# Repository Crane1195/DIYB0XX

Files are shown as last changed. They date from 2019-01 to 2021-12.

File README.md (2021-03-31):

# Crane's DIY B0XXes
### Version 3 - LaserCutB0XX

### Version 2 - AluminumB0XX

### Version 1 - WoodB0XX


The B0XX is a controller designed for Super Smash Brothers Melee, with ergonomics being the number one priority. It is

    Designed by Aziz “Hax$” Al-Yami
    Produced & Engineered by Stephen “Streamlord” Kasmir
    Programmed & Engineered by Kyle “simple” McDowell
    Logo & Art  by Jacqueline "Jisu" Choe

More information regarding the B0XX and links to preorder it are found here.

https://b0xx.com/

To contact me with any comments or questions regarding the info in this repo, join my Discord server here: https://craneslab.xyz/discord

I wanted to try this layout before the product launches, so I created a B0XX from raw materials (later a prefabricated case), arcade hardware, and an Arduino.

I first created a B0XX using wood, which you can see the process of in the MyWoodB0XX folder, but did not like the feeling of its surface and its large size.

I then made one in a much smaller aluminum case that I purchased from Digikey, and have had an acrylic panel laser cut with the layout I drew in Autodesk Inventor. Info about it and its upgrades can be found in the MyAluminumB0XX folder.

I have now made one using a laser cut wooden case, and internally it uses my new GCCPCB which allows for much cleaner internals, and many new features. More info about this build and the GCCPCB can be found in the MyLaserCutB0XX folder.

The process of making the detachable GameCube cable used with my Aluminum B0XX is detailed in the Detachable Cable folder.

The MiniB0XX folder contains files pertaining to a 3d printable case that is similar in size and potential functionality to my Aluminum B0XX.

The code folder includes the most up to date software for flashing to an Arduino.

If sharing any of the files/information found here, give credit where credit is due.

### Support my work

Do note, all Amazon links are affiliated, meaning I get a kickback when you buy anything using these links, and you pay the normal price of the thing. I figure it's a good way for people who want to support me to be able to without any additional cost.

I also set up a donation link for people who appreciate my work and wish to donate. Donations are greatly appreciated, but are far from necessary:

https://www.paypal.com/donate/?hosted_button_id=NFDEML5FKR8N8

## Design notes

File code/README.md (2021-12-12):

# DIYGCC v1.209 code by Crane.

# Deprecated

This firmware has been succeeded by [CL-FW](https://github.com/Crane1195/CL-FW). Consult the CL-FW README for more information and a new installation guide.

---

This is code designed with 16 mhz Arduinos in mind such as the Arduino Mega 2560, Arduino Micro, Arduino Nano, etc.

Release Page: https://github.com/Crane1195/DIYB0XX/releases

## Variants

- `DIYGCC_GC`
  - __**Using:**__
    - Mega2560, Nano, Uno
    - [GameCube circuit](https://cdn.discordapp.com/attachments/557665530677559307/680513973694627847/micro_diyb0xx_schematic.png)
  - __**Supports:**__
    - GameCube/Wii/GCC to USB adapter

- `DIYGCC_GC_And_USB`
  - __**Using:**__
    - Micro, Leonardo, Pro Micro
    - [GameCube circuit](https://cdn.discordapp.com/attachments/557665530677559307/680513973694627847/micro_diyb0xx_schematic.png)
  - __**Supports:**__
    - GameCube/Wii/GCC to USB adapter
    - PC via a USB cable

- `DIYGCC_USB`
  - __**Using:**__
    - Micro, Leonardo
  - __**Supports:**__
    - PC via a USB cable

- `DIYGCC_USB_ProMicro`
  - __**Using:**__
    - Pro Micro
  - __**Supports:**__
    - PC via a USB cable

- `DIYGCC_USB_Switch` - [Read this README for instructions](https://github.com/Crane1195/DIYB0XX/blob/master/code/DIYGCC_USB_Switch_Beta/README.md)
  - __**Using:**__
    - Micro, Leonardo, Pro Micro
  - __**Supports:**__
    - Switch via a USB cable

- `Smashbox`
  - __**Using:**__
    - Hitbox Smashbox
  - __**Supports:**__
    - GameCube/Wii/GCC to USB adapter
  - Here is a tutorial for how to flash it to a Smashbox. Use the code from the most recent release on this repo, as it is the most up to date.
https://github.com/zandm7/DIY-SmashB0XX/blob/master/code/README.md

## SOCD Options
You can choose between 2ip, 2ip with no reactivation, and neutral to resolve simultaneous opposite cardinal direction (SOCD) inputs. This applies to both the control and c stick.

#### 2ip works like this:
* Press left. Character moves left.
* While still pressing left, press right. Character moves right.
* While still pressing left, stop pressing right. Character moves left again.

#### 2ip with no reactivation (The method the B0XX uses) works like this:
* Press left. Character moves left.
* While still pressing left, press right. Character moves right.
* While still pressing left, stop pressing right. Character will not move.

#### Neutral works like this:
* Press left. Character moves left.
* While still pressing left, press right. Character stops moving.
* While still pressing left, stop pressing right. Character moves left again.

## Game profiles
Currently there are 4 game profiles. Melee, Ultimate, PM, and RoA. While plugging in the controller:
* Hold no buttons for Melee.
* Hold B for Ultimate.
* Hold X for PM.
* Hold Z for RoA (only on PC over USB)

## USB Mode
If you are using the firmware with both GC and PC support, hold C-Down while plugging in to enter PC mode.

If you are using any PC supporting firmware, hold ModY on plugin to enter keyboard mode.

## DPAD Toggle
DPAD is enabled by holding ModX and ModY and pressing C-Up/down/left/right.

## Installation
The firmware currently utilizes Nicohood's Nintendo library found here :

https://github.com/NicoHood/Nintendo

and MHeironimus' Arduino Joystick Library found here :

https://github.com/MHeironimus/ArduinoJoystickLibrary

If this is the first time you have used these libraries, press Clone or download, and press Download ZIP on these repos.

Download YourVariant.zip from the latest release here https://github.com/Crane1195/DIYB0XX/releases. Copy the YourVariant folder out from this .zip to a convenient location. You can place the ArduinoJoystickLibrary-master.zip file and the Nintendo-master.zip file here too.



Your folder should look something like this.

Another thing you will need is the Arduino IDE, which is found here :

https://www.arduino.cc/en/Main/Software



After installing the Arduino IDE, open YourVariant.ino within it, and add the libraries using this menu option.



Navigate to where you have the YourVariant folder, and double click one, then repeat the process for the other. You will only need to install these libraries and the Arduino IDE once. For future updates, you will just have to download the new code, and upload it using the method below.



In this menu, change the board to be whichever board you are using. If you are using a Pro Micro you can just use the Micro option. 



Before plugging in the Arduino, look and see what Ports are there. On this machine, there is COM1, but on my other machine, I had none.



Plug in the board via USB, and check this menu again, you should see another COM port show up. For both of my computers, it will also say "Arduino Micro" next to the port, but it is possible it will not. What should always happen though, is a port should show up when you plug in the board, and should disappear when you unplug the board (make sure you close the menu and reopen it to refresh the list). This port is the port for your Arduino, so select it.



If you are using GC firmware, you will need to change the value here to match which pin you connected your data line to.



On any of these firmwares, you will need to change this pinout section to match which pins you connected your buttons to.



Click this button to upload the firmware to the Arduino.



This section of the IDE will say Compiling Sketch, then Uploading, then Done Uploading. When it says Done Uploading, the board is ready to use, and can be unplugged.

## Contact info
Let me know if you have any issues with the code in my Discord Server:
https://craneslab.xyz/discord

## Support my work

Do note, all Amazon links are affiliated, meaning I get a kickback when you buy anything using these links, and you pay the normal price of the thing. I figure it's a good way for people who want to support me to be able to without any additional cost.

I set up a donation link for people who appreciate my work and wish to donate. Donations are greatly appreciated, but are far from necessary:

https://www.paypal.com/donate/?hosted_button_id=NFDEML5FKR8N8

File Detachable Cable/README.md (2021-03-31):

# Crane's Detachable Gamecube Cable Guide


Here you will find all the information needed to make a detachable cable for a custom Gamecube controller/fightstick.

If you have any questions regarding the process, feel free to ask in my Discord server here https://craneslab.xyz/discord

GCC stands for GameCube Controller. I will use this acryonym a lot.

## Required Parts / Tools


- OEM GCC Cable OR GCC extension cable
    - If you have a broken GCC for parts, you can harvest its cable and use that. Otherwise, a GCC extension cable will work. If you have neither, a broken GCC costs much more, but its cable is guaranteed to be high quality, as it is OEM. An extension cable is much cheaper (talking ~$15 dollars compared to ~$3), but some of them are not high quality.
    - I made two custom cables from Kitsch-Bent extension cables and they work perfectly. Here is a link to them, select NGC from the drop down menu. They only cost $2.50, and shipping is ~$5.00, so I got multiple.
    - http://store.kitsch-bent.com/product/extension-cables

- Wire stripper. This is used to remove the protective outer shell of the GCC cable.
    - I used the 8/10 gauge cutter on mine.

- RJ45 Crimp Kit
    - Here's the kit I used. This comes with both the crimping tool, and the connectors.
    - https://amzn.to/2QNOFHn

- Neutrik NE8FDP
    - This is the female connector that gets installed in the case of the fightstick; comes in black and silver. Here's a link to the black one I use.
    - https://amzn.to/3frK87Z

- Neutrik NE8MC
    - This is the male connector, that is installed around the custom cable. The cable works without this, but this makes it much more durable and secure; also comes in black and silver. Here's a link to the black one I use.
    - https://amzn.to/39usFYx

- Multimeter
    - If you are not using an OEM GCC cable, to be safe, you will need to check which wire is which signal. I will post what my wires are below. If you use a Kitsch-Bent extension, they will likely be the same, but not necessarily. It is possible that they have changed their supplier which would change the wiring.

## Making the Cable



1. Cut the female end off of the extension cable, or take apart a GCC and cut the cable as close to its connector as possible.



2. Strip off about 1 cm of the outer shell. The wires here are too long, so I trimmed them down as seen below, using a wire cutter.



3. Flatten all the wires in a way that makes them the least strained. In the cable, they are in a hexagonal prism formation, so try and keep the left wires close to the left, right to right, and middle to middle.



4. Insert the cables into a connector like so, with each wire going into its own channel.



5. This is the wiring setup I am using. As shown in the graphic on the right, the 8 channels of an RJ45 jack are numbered from left to right when the connector is pointing away from you, and the tab is pointing down.

There are different standards of RJ45, but the T-568B RJ45 cables are what you will probably find when getting an "ethernet" cable, and it is what I have on hand.

Row 2 shows which channels the wires from my GCC extension cable are in, Row 3 shows the T-568B wires, and row 4 shows what    function each wire serves for this cable. I will show how I derived this further down.



6. Push the connector into the side of the crimping tool that it fits into (it only fits one way) while keeping the cable pushed all the way into connector. I clamp it down 3 times with full force. The cable should now be clamped down by the plastic connector.


7. To find which cable does what, I then cut a ethernet cable in half, cut open its out shell, and strip the ends of the wires. I used a 26 gauge wire stripper for this.


8. I then plugged the GCC to RJ45 cable and the cut ethernet cable into the Neutrik ethernet passthrough.


9. Using a multimeter on continuity mode, attach one lead to one of the exposed ethernet wires, and then stick the other lead into the GCC male connector, and find which pin corresponds to which wire.


10. To double check this, you can check the wires voltages as well. Using the same setup as before, with GCC to RJ45 to Neutrik to RJ45 to breakout. Make sure the exposed wires stay fanned out like in the picture to prevent a short circuit. Hook up the GCC plug to a GC/Wii/Adapter, and read the difference in voltage between the wires you think are 5V/3.3V/Data and ground. The 5V one will read ~4.7V, the 3.3V one will read ~3.1V, and the data one changes, but is less than ~3.3V and greater than ~0.1V.

Using both of these methods, I derived the chart you see above for my cable. If you use a different extension cable, or a different standard of RJ45 ethernet cable, or different wire order, our charts will not be the same. If you use a Kitsch-Bent extension cable, and line up its wires just like I did, it'll probably be the same, but you should check anyway just to be safe.


11. Follow the instructions here to install the NE8MC around your new cables RJ45 plug.

https://www.neutrik.com/media/8070/download/ethercon-cable-connector-ne8mc.pdf?v=1

## Installation Into a Fightstick


12. I used a unibit to drill a ~24mm hole in this aluminum case, inserted the NE8FDP faceplate into the hole, marked where the screw holes should be, and drilled 1/8" holes for them.


13. Inside the case, I cut that ethernet breakout cable down very short, trimmed the wires to be just long enough, and then soldered them into place. For more information about this wiring schematic, check out the README here. https://github.com/Crane1195/DIYB0XX/tree/master/MyAluminumB0XX

## Results

I ended up making a second one as I wasn't taking pictures as I went for the first one. As previously mentioned, it works without the NE8MC, but I'd still recommend it for a more secure connection.

Once again, let me know in my [Discord Server](https://craneslab.xyz/discord) if you have any questions.

## Support my work

Do note, all Amazon links are affiliated, meaning I get a kickback when you buy anything using these links, and you pay the normal price of the thing. I figure it's a good way for people who want to support me to be able to without any additional cost.

I also set up a donation link for people who appreciate my work and wish to donate. Donations are greatly appreciated, but are far from necessary:

https://www.paypal.com/donate/?hosted_button_id=NFDEML5FKR8N8

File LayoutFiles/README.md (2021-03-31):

# Layout Files

I've made a lot of layout files over time and figured it would make sense to compile some of the useful ones here. Let me know if you interested in any other layout files, I might have made them already and I can add them here.

The PDF folder is for people who want to print the layout to use as a template.

The DXF folder is for people who want to modify the layouts, or get them laser cut.

## USA Laser Cutting Recommendations

https://www.pololu.com/product/749 for laser cutting acrylic and wood, they are very fairly priced and quite quick.

https://sendcutsend.com/ for laser cutting metals, they have incredible prices for laser cut metals, are super fast, and offer free shipping.

## Top Panel Laser Cutting Advice

### MX Form Factor Keyboard Switches

If you are using MX like keyboard switches, I recommend using a 1.5mm steel switch plate from SendCutSend. 1.5mm is what you need for the switches to snap in properly, and steel is super rigid and not too expensive. Acrylic and wood would be far too flimsy, aluminum would probably be fine but a bit less rigid than steel, and brass/carbon fiber would work well but be far more expensive.

### Snap In Buttons

If you are using 24mm snap in buttons (like Sanwa OBSX-24) and an acrylic or wood top panel from Pololu:

Sanwas will only clip into panels that are <= 3mm thick with 24mm holes. Just a 3mm thick top acrylic panel though will flex in the middle. To solve this, I add another 3mm panel beneath the top panel. This one has 26mm holes, which allows the buttons to still clip in.

```
Top Top panel    - 3mm thick - 24mm holes
Bottom Top Panel - 3mm thick - 26mm holes
```

If you are using 24mm snap in buttons (like Sanwa OBSX-24) with an aluminum or ACM top panel from SendCutSend, ~3mm is enough to not flex at all.

### Screw in Buttons

If you are using Crowns screw in buttons you could use just one 6mm acrylic or wood panel with 24mm holes rather than two 3mm ones. (Unless you want art, then you'd want a clear 3mm panel and some color 3mm panel)

And like with snap in buttons, just a 3mm aluminum or ACM panel is fine too.

### Support my work

Do note, all Amazon links are affiliated, meaning I get a kickback when you buy anything using these links, and you pay the normal price of the thing. I figure it's a good way for people who want to support me to be able to without any additional cost.

I also set up a donation link for people who appreciate my work and wish to donate. Donations are greatly appreciated, but are far from necessary:

https://www.paypal.com/donate/?hosted_button_id=NFDEML5FKR8N8

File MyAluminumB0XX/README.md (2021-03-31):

# Crane's DIY Aluminum B0XX


The B0XX is a controller designed for Super Smash Brothers Melee, with ergonomics being the number one priority. It is

    Designed by Aziz “Hax$” Al-Yami
    Produced & Engineered by Stephen “Streamlord” Kasmir
    Programmed & Engineered by Kyle “simple” McDowell
    Logo & Art  by Jacqueline "Jisu" Choe

More information regarding the B0XX and links to preorder it are found here

https://b0xx.com/

While my first DIY B0XX project was functional, it had room for improvement. This time, I have chosen to purchase an aluminum case from Digikey to use as the chassis, and I have drawn a face plate, which was laser cut out of acrylic from Pololu. The prefab aluminum case was chosen to make all three dimensions smaller. It is much more portable now as a result. The laser cut acrylic plate has perfectly spaced holes, and is much smoother than the wood coated in polycrylic.

On top of this, I have done two modifications to the design which increase overall functionality.



The first of which a detachable RJ45 to Gamecube cable, and the second is an internal Gamecube to USB adapter with the extra three ports available to use outside the case.

If you have any questions regarding this build, feel free to ask me in my Discord server (https://craneslab.xyz/discord) or in direct message @Crane#1195 .

## Components

### Aluminum Case


The case used for this build is a 12" x 8" x 2" aluminum prefab that I ordered from Digikey.

https://www.digikey.com/product-detail/en/hammond-manufacturing/1444-22/HM267-ND/247996

This case's edges are pretty sharp, the holes on mine did not match up exactly to its datasheet, and it got pretty scratched up while I was modding it, but it is pretty decent for the price of ~$40 dollars shipped.

A bit of sanding solves the sharp edges.

I highly reccomend measuring the holes on your unit if you are making a panel for the top like I did. I might have been unlucky, but it might be normal.

It comes with an adhesive protective film on all sides if I recall correctly. Leave these on the case while working on it.

They also make a similar case to this one, but in a 16" x 8" x 2" form factor. The larger size comes in both aluminum:

https://www.digikey.com/product-detail/en/hammond-manufacturing/1444-26/HM269-ND/247998

and steel:

https://www.digikey.com/product-detail/en/hammond-manufacturing/1441-26BK3/HM1493-ND/460097

I have not used the steel variant, but I would imagine it would be more scratch resistant and probably stronger.

### Laser Cut Acrylic Button Panel


I designed this button panel based on the layout of the MiniB0XX made by Simple. You can find drawing/PDF files of this layout here:

https://github.com/Crane1195/DIYB0XX/tree/master/MyAluminumB0XX/AcrylicPlate

I sent drawing file (.dwg) to Pololu, who have an affordable acrylic laser cutting service that you can find here:

https://www.pololu.com/product/749



They have tons of options, and I chose this one. It is a slightly translucent matte finish white panel (the bottom side is glossy, but it is inside the case).

I highly recommend them. I have ordered two panels from them so far, and both turned out perfect. Do note though, this panel is below their minimum cost of $25, so if you have anything else you would like laser cut, they can add that to the order to be cost efficient.

The screw holes in the drawing file I linked is based on the 12" x 8" case's datasheet's screw placements, and as previously mentioned, these did not work perfectly for my case. I had to use different screws and angle them for the top two. Measuring your own case and editing the drawing file would be ideal, and if you do not know how to use a CAD software, or do not have one, I can edit the drawing for you given your measurements. Alternatively you could just roll the dice and hope your case is good enough, or angle screws like I did.

Personally, I use just one 3mm acrylic panel for the top. If you push in the middle of it, there is a bit of flex, but it is not enough to bother me. If this would bother you, or you want to easily use art under the buttons, you can get a second panel, but with 28mm holes to put under the top 24mm holes panel. This way, the buttons snap into the top panel, and just pass through the second. For art, you could get a clear top, and whatever color bottom, and put the art inbetween. Once again, if anyone who can not use a drawing editor wants me to make this into a file, let me know.

### Detachable RJ45 to GCC Cable

This is a massive upgrade over the attached cable used previously. Besides the fact that the cable I used was in bad shape and from a beat up OEM controller I found on eBay, an attached cable does not really have anywhere to go outside of a box controller. Wrapping it around damages the cable, and it makes the controller much more of a hassle to travel with. To see how this cable is made, check out this guide I wrote on the topic: https://github.com/Crane1195/DIYB0XX/tree/master/Detachable%20Cable

### Internal GCC to USB adapter

This is an interesting addition that could be quite useful for some people, but I am not really one of them. Basically, you take the Nintendo GCC to USB adapter out of its case, solder wires to the pads of a GC port on a Gamecube to USB adapter, and route those to the same lines of your normal GCC cable. What this means is that you can use the controller like a normal Gamecube controller with the RJ45 to GCC cable, or you can plug the GC adapters USB cable into a Switch/WiiU/PC to avoid using an external controller adapter.

To do this, I wanted to remove the gray usb cable to save space in the case, and solder wires to the back of the adapters PCB to access 5v, GND, 3v, and data.


Here is a spreadsheet detailing what each pin of the connector / header on board does.


Basically you want to remove / cut wires 1, 2, and 5, and split the cable in half as seen below.


Here is the finished modified GCC adapter. I forgot to get a labeled pinout of the pads on the back of the adapter as to which is 5v, GND, 3V, and data, so if you want to do something like this, you'll need to use a multimeter continuity test to figure out which is which.

### The Internals

Initially, I had used the same Mega2560 and logic converter as before, and soldered each of the GCC adapters lines (5v, GND, 3v, Data) to the RJ45 lines.

### Wiring Schematic

The wiring schematic is the same as my first DIY, but now has the GCC adapters lines attached as well.

### Completed interior

Not the cleanest thing ever, but here was the completed interior. The left Neutrik is for the Dween, the middle is for the RJ45 Gamecube port, and the right is for the GCC to USB adapter.

### Updated interior

I made a PCB to make building Gamecube controllers a lot easier and to have more features. I call it the GCCPCB. A brief synopsis of the benefits are:

* The entire circuit is all done by the board.
* Buttons don't need to be spliced to jumper cables and can just be plugged into screw terminals.
* It's very compact.
* A port for a detachable cable is built in (either RJ45 or USBC).
* A 10x2 pin connector is on board to passthrough button signals to a Brook board.
* Native PC controller support. No need for a GCC to USB adapter for PC.
* Nunchuk port to use an analog stick instead of the digital stick / modifiers.

If you are interested in finding out more about the GCCPCB, check out https://www.craneslab.xyz/projects/s


Here is the final interior. I put a four pin header on the board to allow access to the 5V, GND, 3V, and Data lines so I could hook up my GCC to USB adapter. I plugged the GCC adapter into the GCCPCB USB port, which means that it is accessible using a RJ45 to USB cable. The Arduino is plugged into a USB Neutrik, which I use for Native PC control and updating the firmware.

### Conclusion / Contact

Overall, this controller has been a really solid test bench for various projects I've been working on. First the internal USB to GCC adapter, then my mechanical switch boards that I used to replace the Sanwa SW68s (maybe more info on these coming soon, they aren't perfect yet), and now to work on my GCCPCB.

If you have any questions about this build, the GCCPCB, or anything else, feel free to message me on Discord @Crane#1195, or to join my Discord server, https://www.craneslab.xyz/discord, where I'll be posting updates about the various projects I am working on.

### Support my work

Do note, all Amazon links are affiliated, meaning I get a kickback when you buy anything using these links, and you pay the normal price of the thing. I figure it's a good way for people who want to support me to be able to without any additional cost.

I also set up a donation link for people who appreciate my work and wish to donate. Donations are greatly appreciated, but are far from necessary:

https://www.paypal.com/donate/?hosted_button_id=NFDEML5FKR8N8

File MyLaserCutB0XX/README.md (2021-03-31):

# Crane's Laser Cut DIY B0XX



The B0XX is a controller designed for Super Smash Brothers Melee, with ergonomics being the number one priority. It is

    Designed by Aziz “Hax$” Al-Yami
    Produced & Engineered by Stephen “Streamlord” Kasmir
    Programmed & Engineered by Kyle “simple” McDowell
    Logo & Art  by Jacqueline "Jisu" Choe

More information regarding the B0XX and links to preorder it are found here

https://b0xx.com/

Up until now, I haven't actually made a "perfect" DIY B0XX, which I define as thin, a spread out layout, and high build quality. I've accomplished these three this time, as well as doing art and using my USB-C GCCPCB for the first time.

## The Laser Cut Case

The case is comprised of 5 laser cut layers, all cut by [Pololu](https://www.pololu.com/product/749). A big shoutout goes to simple for the layered case idea.

- Bottom Layer      : 1/4" Wood

- Wall Layer 1      : 1/2" Wood

- Wall Layer 2      : 1/2" Wood

- Top support layer : 1/8" Wood. 26mm holes cut for buttons to pass through.

- Top button panel  : 1/8" Transparent cast acrylic. 24mm holes cut for buttons to snap into.


Here's a picture of all five layers and the hardware to secure it all.


The bottom wall panel has hexagons cut to hold hex nuts within the walls of the case to hold the screws in place. Since the hex nuts are thinner than the wall, I 3d printed hexagon shaped spacers to put underneath the nuts (shoutout to simple for this idea).


The nuts now sit flush with the top of the wall. The second wall is glued on top of this wall, encasing the nuts within the walls.


Here's how it looked after the bottom and the two walls were glued together. The top two panels get screwed into the bottom 3.


I didn't have a way to perfectly align the layers as they were being glued together, so the layers were about 0.3mm off at various points around the case. If anyone plans on doing a case like this, I reccomend figuring out a way to make sure they are perfectly aligned while gluing to prevent this. If I end up doing this again, I will put the same size hole as in the walls in the bottom panel and put a rod through all the panels holes to try and hold it in place. I'd probably then wood fill in the holes in the bottom panel.


I decided to sand the entire thing so that they would be even. This took a long time considering I only have a sanding block.


I then put the acrylic panel on it, and went at it again. I got a lot more of the laser burn off this time as well.


After sanding was done, I used Minwax prestain conditioner, then 2 layers of dark walnut stain, then 3 layers of liquid clear satin polyurethane, then one layer of aerosol polyurethane. Finally I used wood finishing paste wax on top of all that. After all the sanding, polyurethane, and wax, it's about as smooth as my satin hardwood floors.

## Art

Next was art. I printed it on 17"x11" paper, used scissors to cut the rounded edges, put it inbetween the two panels, and used an exacto knife to cut out the button holes. I then used the white spacer in the OBSC-24 button to give me a guide for how small the button art had to be. I used a very small pair of scissors to cut the 24mm art cutouts down to the size they needed to be to fit in the buttons. [Here's a rough guide on that if you are interested.](https://support.focusattack.com/hc/en-us/articles/115002742306-Adding-art-to-buttons-101)

## Ports

I left two gaps in the walls. One for a [USB C feedthrough](https://amzn.to/3ud6Y7w), and the other for a [Nunchuk extension cable](https://amzn.to/3u9P2dJ). The company who makes the USB C feedthrough also makes one with only one port which you can find [here](https://amzn.to/39NfIth).

Here is another [USBC feedthrough](https://amzn.to/2PeNWPh) which is more commonly in stock and is usually cheaper.


I used [this](https://amzn.to/3diyg5o) to secure the USB C feedthrough in place, and the Nunchuk extension is friction fit into place. Both are very secure, and I will eventually get some black PLA and make a spacer above the Nunchuk extension to close that hole.

## Internals

Here you can see the internals. This board is the GCCPCB, made my me. If you are interested in learning more or have any questions about this board and its firmware, feel free to message me about it on Discord @Crane#1195, or to [join my Discord server](https://www.craneslab.xyz/discord) where I post updates about hardware I am working on or firmware updates.
Here's a brief synopsis of its benefits over my previous method of making DIY Gamecube Controllers.
* The entire circuit is all done by the board.
* Buttons don't need to be spliced to jumper cables and can just be plugged into screw terminals like on a Brook board.
* It's very compact, which is crucial in this build considering how small the interior of the case is (15" x 7" x ~0.9")
* A port for a detachable cable is built in (either RJ45 or USBC). I chose USB C for this build.
* A 10x2 pin connector is on board to passthrough button signals to a Brook board (I won't be doing it for this build)
* Gamecube/Wii and WiiU/Switch (with a GCC to USB adapter) supported with the USB-C to GCC cable [sold here](https://b0xx.com/products/usbc)
* Native PC controller support. No need for a GCC to USB adapter for PC.
* Nunchuk port to use an analog stick instead of the digital stick / modifiers.


Due to how thin the case interior is, the board and all the patch cables all needed to be in a position that was not directly underneath a button. It took quite a while to actually find a location where this was true, and the spot I picked might be the only spot.


Unintentionally, the LED on the board ended up being almost directly under the start button giving it this neat faint glow that only shows up in a dark room.




A few more angles.

### Conclusion / Contact
Overall I'm super happy with how this turned out. It isn't perfect, but it is about the best I could have done given my inexperience with fightstick art and laser cutting cases. I learned a lot and would it would definitely be easier the next time I do one like this.

If you have any questions about this build, the GCCPCB, or anything else, feel free to message me on Discord @Crane#1195, or to join my Discord server, https://craneslab.xyz/discord, where I'll be posting updates about the various projects I am working on.

### Support my work

Do note, all Amazon links are affiliated, meaning I get a kickback when you buy anything using these links, and you pay the normal price of the thing. I figure it's a good way for people who want to support me to be able to without any additional cost.

I also set up a donation link for people who appreciate my work and wish to donate. Donations are greatly appreciated, but are far from necessary:

https://www.paypal.com/donate/?hosted_button_id=NFDEML5FKR8N8

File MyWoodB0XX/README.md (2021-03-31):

## Crane's DIY B0XX



First, credit where credit is due. The B0XX is a product made by:

Hax$ (https://twitter.com/ssbmhax)

Streamlord (https://twitter.com/StreamlordSSBM)

SimpleControllers (https://github.com/SimpleControllers)

Their website, where the B0XX is now available to preorder, is http://b0xx.com/

Here you can find the B0XX manifesto explaining how the B0XX attempts to be in line with the gamecube controller for SSBM, among other references.

Huge shout out to Simple for his guide detailing how to DIY a Smash Box found here. This is how I learned how to wire up the controller. Since then I have made a cleaner and more updated wiring schematic so be sure to follow mine instead. Scroll down to see it.
https://docs.google.com/document/d/1ndV4E_w2ThAv9LpbjEzRDWwMj0uBWB9YqbvkHV35X5w/edit

I've made code for DIYB0XXes that you can find here. It has Melee, PM, and Ultimate modes, and acts very similar to the official B0XX.

https://github.com/Crane1195/DIYB0XX/tree/master/code

This utilizes the Nicohood Nintendo library found here https://github.com/NicoHood/Nintendo

Anyway, enough of the intro, lets get into the build.

### Part List
  * Arduino ~~Mega 2560~~ Micro (Third party ones are cheaper, and work just as well. I have used this one https://amzn.to/3wioVTG)
  * Logic Controller 3.3V - 5V (I used this one https://amzn.to/3m78dSC)
  * 18 Sanwa OBSF-24 buttons
  * GameCube controller cable. This can be either the cable from an OEM controller as shown in this build, a 3rd party controller cable, or a 3rd party extension cable. You can make this cable detachable by following the guide here https://github.com/Crane1195/DIYB0XX/tree/master/Detachable%20Cable
  * The wooden case
  * 15/16" spade bit
  * 18 .110" QDC button wires
  * .110" daisy chain ground wire
  * Male to male jumper wires
  * Heat shrink kit



For a joke, I made the greatest piece of tech that the world has ever seen with the shoeb0xx.

Pictured is the wood used to create a more sturdy B0XX. For a thinner, more slim B0XX, you could use metal, plastic, plexi, or plywood for the top. I wanted a sturdy platform so I used 0.75 inch thick wood, as I don't have the tools to work with metal, plastic, etc. The actual size of the B0XX is 16" x 8" x 1.4", however I could not find a piece of wood exactly 8 inches deep, with the closest I found being 9.75". I don't have a saw that can make the cut, so I stuck with the 9.75" depth. I don't mind it, as I can use the extra depth to rest my wrists.



I cut the wood to about the correct size using a compound miter saw.



Using wood glue and clamps, I joined the sides together.



I tested the fit of the top with the curing walls.



I wood glued the top to the walls, and applied tons of pressure using clamps and some textbooks to join the wood.



This is the only picture I could find of the finished pure wooden B0XX, with the Arduino that just showed up.



Here's a link to a 17" x 11" PDF of the layout https://drive.google.com/drive/folders/1cv-wkTo0xmuKJOSA2eP_3mJmC4tP5-0d?usp=sharing

I'll be making a folder on this repo soon with CAD files / more detailed instructions for making faceplates.

Taping the template to my B0XX, I marked the center points with a thumbtack.



This is the B0XX after cutting the holes with a 15/16" spade bit.



I cut a piece of 2' x 2' piece of plywood to be the bottom. As I write this, the paint is drying on the bottom. I did this last.



I painted the top and sides using multiple layers of spray paint, and then brushed on 3 layers of minwax polycrylic to make it smoother and a bit more protected.



Next up was the internals. Here you can see the OBSF-24 Blues and the cables I spliced together to connect the buttons to the Arduino.

Edit : Do note, I used to use the Arduino Mega 2560 seen here, and solder spliced wires for the buttons. I recommend not doing this though, and instead using an Arduino Micro like the one linked in the part list. The wiring schematic below has been updated to reflect this.
The reason to pick the Micro instead is that it can work as a controller on PC without a Gamecube Controller to USB adapter. The Mega2560 cannot. Also, just soldering the button wires to the board is a lot easier IMO then solder splicing wires.

Message me if you have any questions about the Arduino Micro.

Custom wire process:
* Bought a pack of 10 double ended cables with .110" QDC's and cut them in half
* Cut male to male jumper wires in half
* Strip the ends of these wires
* Solder the ends together, and put heat shrink over the joint.

Also pictured is a Gamecube controller cable that I desoldered from a dead GCC I bought from ebay.



The wiring is messy since I made the cables much longer than they need to be unfortunately. I used a common ground daisy chain cable with 30 .110" connectors, a 5v to 3.3v converter, and a common ground / 5V panel from another project I did.



Here is a wiring diagram I made showing how it all works. I previously used a Mega2560, but now I use an Arduino Micro. I've updated the schematic to show this. For more info on how the wiring works, feel free to ask in my [Discord Server](https://www.craneslab.xyz/discord)



First time testing it with my GC! Works flawlessly.



The color scheme was done to match my mechanical keyboard.



Another angle



Immediately after drilling a 3/8 inch hole for the Arduino's USB port, I remembered that I have a jigsaw. Used a knife to square it out a bit so the usb could fit, but it isn't as clean as a jigsaw would've been.



Here is an extensive part list I made to track how much I spent but I thought I'd share.



Once again, huge thanks to Simple for his guide, and assistance when I had a couple of roadblocks, as well as Hax, and Streamlord.

## Support my work

Do note, all Amazon links are affiliated, meaning I get a kickback when you buy anything using these links, and you pay the normal price of the thing. I figure it's a good way for people who want to support me to be able to without any additional cost.

I also set up a donation link for people who appreciate my work and wish to donate. Donations are greatly appreciated, but are far from necessary:

https://www.paypal.com/donate/?hosted_button_id=NFDEML5FKR8N8

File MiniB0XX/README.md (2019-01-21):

### I did not design the files found in this folder. They were made by simple, and I have received his permission to add them to this repo to have all do it yourself B0XX information in one place, for the purpose of organization.

### I did edit his files to add support for detachable cables. These edits are found in the Detachable MiniB0XX folder.

The MiniB0XX is a 11.5" by 8" shrunk version of the B0XX designed by simple to be 3D printed.

The files in the folder "Original MiniB0XX" are the printable STL files posted by simple in the 20XX discord in DIY #resources

The files in the folder "Detatchable MiniB0XX" are edits I made to the original to allow for detatchable cables with Neutrik passthroughs.

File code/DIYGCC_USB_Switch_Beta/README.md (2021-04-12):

## Switch USB Beta Branch

This firmware is a beta version of my code which works on the Switch over USB courtesy of Jas2o's fork of MHeironimus' Arduino Joystick Library.

You can find this library here: https://github.com/Jas2o/Leonardo-Switch-Controller

It is being redistrubed in this repository following the GNU LGPL v3.0 license. See the LICENSE file in this folder for what that entails.

GameCube functionality is not present on this patch, and the Switch support breaks PC support at the moment. It may be possible to have both working on the same firmware in the future though.

## Installation Instructions

Download the latest release of this code from here:
https://github.com/Crane1195/diyb0xx/releases

Copy the `boards.txt` file found in the release to this file path in your Arduino installation.



Open `DIYGCC_USB_Switch_Beta.ino` in the Arduino IDE, and select Leonardo Pokken from the boards menu.



Plug in the Arduino. Close and reopen this menu and you should see a new com port, this is your Arduino. Select that port.



Modify the pinout section of the code to match your pinout.



Press upload.



If you encounter any errors when installing this firmware, feel free to contact me in my [Discord Server](https://www.craneslab.xyz/discord).

## Support my work

Do note, all Amazon links are affiliated, meaning I get a kickback when you buy anything using these links, and you pay the normal price of the thing. I figure it's a good way for people who want to support me to be able to without any additional cost.

I set up a donation link for people who appreciate my work and wish to donate. Donations are greatly appreciated, but are far from necessary:

https://www.paypal.com/donate/?hosted_button_id=NFDEML5FKR8N8

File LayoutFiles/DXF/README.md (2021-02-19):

# DXF Layouts

I made these DXFs in Fusion360, and they should be importable in most CAD programs that support DXF.

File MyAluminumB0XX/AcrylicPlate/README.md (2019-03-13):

### Standard


A 12" x 8" B0XX layout that I drew in Autodesk Inventor. Has holes for connecting it to the aluminum case.

This can be printed to use as a template for a drill press, or used with a laser cutter.

I sent this file to be laser cut by Pololu, whose service you can find here

https://www.pololu.com/product/749

### GuitarHeroB0XX



This is a layout made by Streamlord where you hold the B0XX like a guitar (see https://twitter.com/Streamlord20XX/status/1015047978841600001).

The DWG file can be used to make edits, or to be laser cut by Pololu.

The PDF file can be printed at a 1:1 scale on standard printer paper (8.5 x 11) and used with a hand drill or drill press.

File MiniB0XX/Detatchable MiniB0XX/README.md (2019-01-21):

## Disclaimer, I have not printed these edited versions of the MiniB0XX, as I do not have a 3d printer. The holes I made in it in theory should work, as they match up exactly to the product pages diagrams, but I cannot confirm with 100% certainty that these designs are flawless. If you end up printing one, let me know if the holes fit the passthroughs.

When printing these,

    "Print outsides facing on bed so you get a glossy face plate and backplate.
    Uses #6 Countersunk Flat head screws 3/4".
    Design is in inches, so make sure you convert to 2540% scale if using mm."
        -simple
I converted simples stl files for the MiniB0XX to ipt files, and then edited those to have holes for Neutrik passthroughs. These ipt files are found in the `.ipts` folder.

The Neutrik passthroughs on the MiniB0XX allow for a detachable RJ45 male to Gamecube male cable and/or an external usb port to connect to the Arduino for updating software.

The folder `Both` contains the stl files for having both ports, and the `JustRJ45`/`JustUSB` folders have the files for just one port.

For `JustRJ45`, you will have to open the MiniB0XX up to change the software.

For `JustUSB`, you will have a non detachable Gamecube cable.

For more information regarding how to make a RJ45 male to Gamecube male cable and how to use one in a DIYB0XX, check this guide out.

https://github.com/Crane1195/DIYB0XX/tree/master/Detachable%20Cable

Here is a link to the product page of the RJ45 passthrough. https://www.neutrik.com/en/product/ne8fdp-b



Here is a link to the product page of the USB passthrough. https://www.neutrik.com/en/product/nausb-w-b



These both come in black and silver.

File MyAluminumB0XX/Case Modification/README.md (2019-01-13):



A 8" x 2" template that I drew in Autodesk Inventor to drill out holes for the adapters extra GameCube controller ports in my Aluminum B0XX.

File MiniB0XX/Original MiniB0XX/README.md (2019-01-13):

When printing these,

    "Print outsides facing on bed so you get a glossy face plate and backplate.
    Uses #6 Countersunk Flat head screws 3/4".
    Design is in inches, so make sure you convert to 2540% scale if using mm."
        -simple

These are the original files designed by simple

B0XX.stl


LID.stl


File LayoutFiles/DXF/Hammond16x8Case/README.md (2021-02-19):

# Hammond 16" x 8" Steel Case

This is a case I have recommended for a while now and is one a lot of people use. It is a 16" x 8" x 2" steel case with an open top that you could screw a switch plate onto.

The model number is 1441-26BK3, and it's available on many sites such as Digikey, Mouser, and Arrow. I would recommend shopping around to find whichever is cheapest at the time.

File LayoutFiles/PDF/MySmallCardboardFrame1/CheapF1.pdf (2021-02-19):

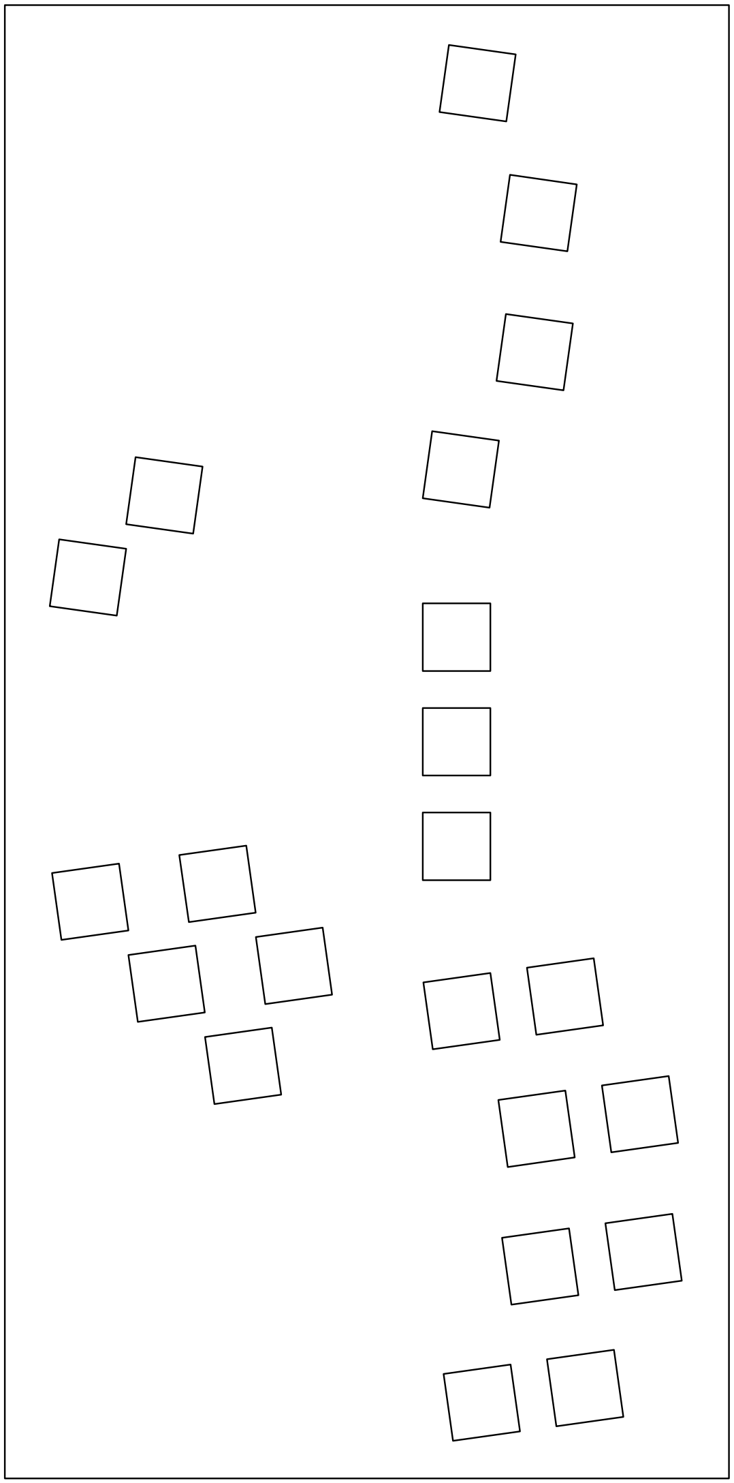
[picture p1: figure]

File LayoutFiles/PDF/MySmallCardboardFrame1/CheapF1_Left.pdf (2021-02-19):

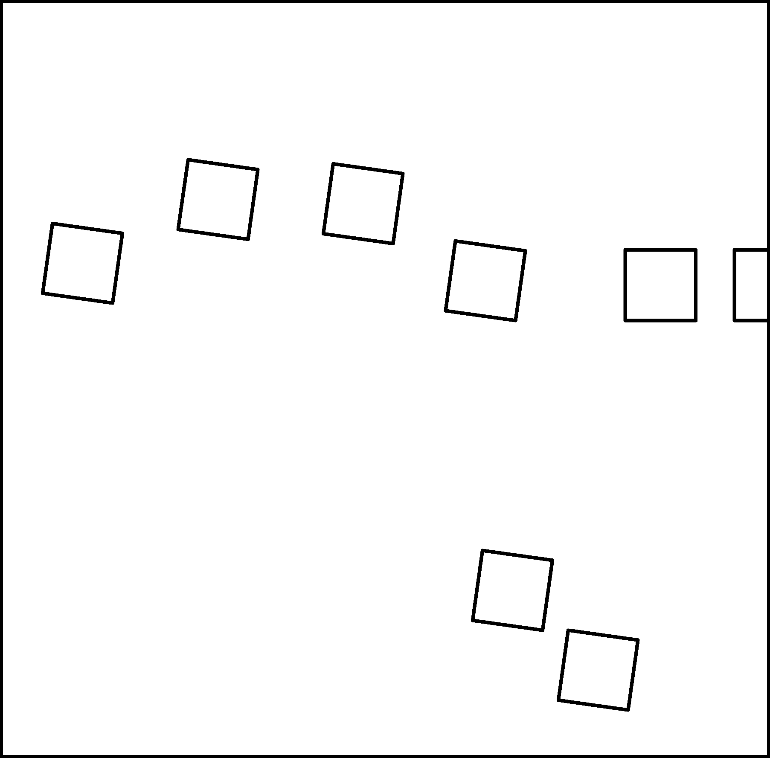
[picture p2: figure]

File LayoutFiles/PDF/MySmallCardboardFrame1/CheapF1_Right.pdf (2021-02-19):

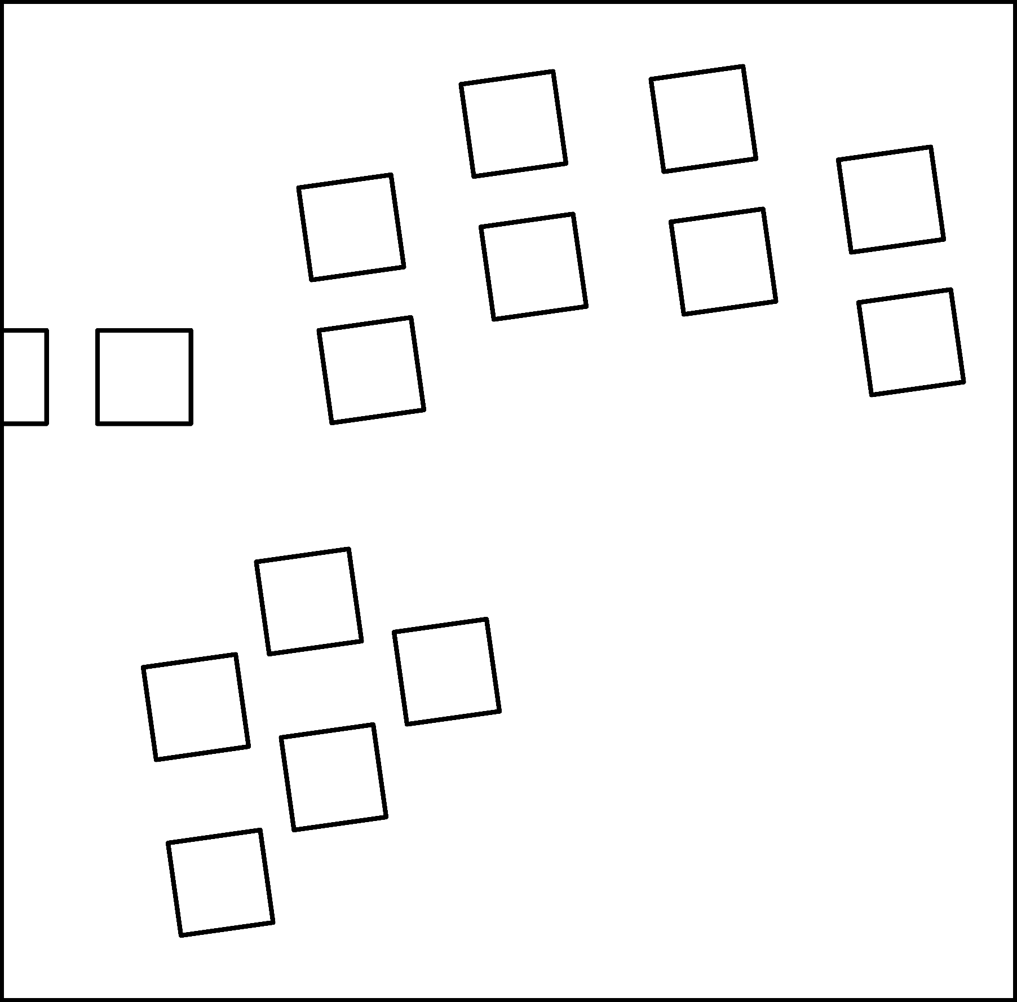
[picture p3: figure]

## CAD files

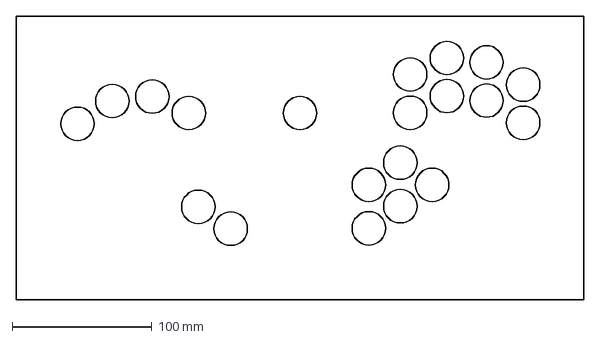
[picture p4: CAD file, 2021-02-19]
LayoutFiles/DXF/B0XX_24mm_TopPanel.dxf
406.4 x 203.2 mm

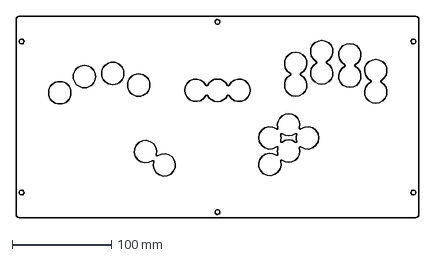
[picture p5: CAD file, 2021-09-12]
LayoutFiles/DXF/Hammond16x8Case/Hammond_LargeCircleCover.dxf
406.4 x 203.2 mm

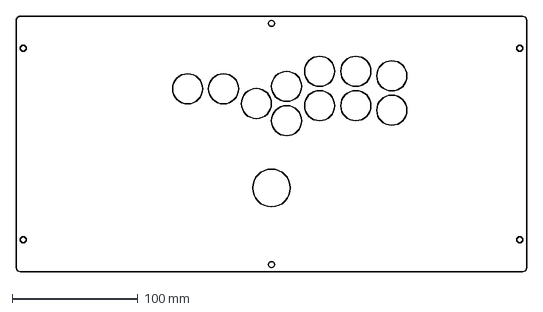
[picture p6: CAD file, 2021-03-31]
LayoutFiles/DXF/Hammond16x8Case/Hitbox/Hammond_24mm_TopPanel.dxf
406.4 x 203.2 mm

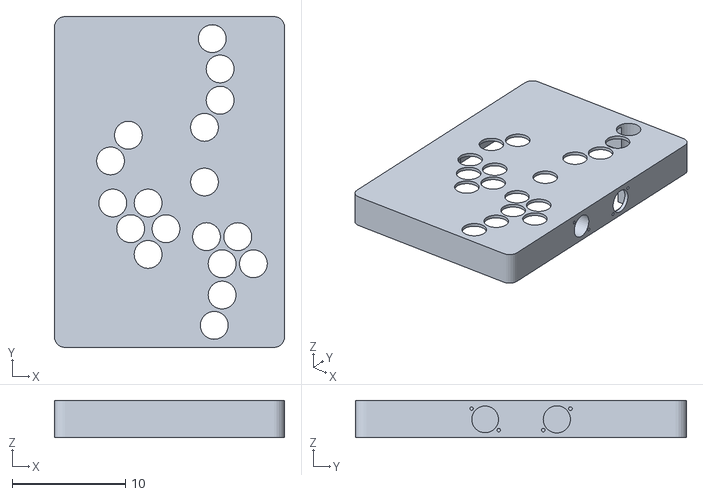
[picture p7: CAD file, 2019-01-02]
MiniB0XX/Detatchable MiniB0XX/Both/DetatchableB0XX.stl
20.3 x 29.2 x 3.30

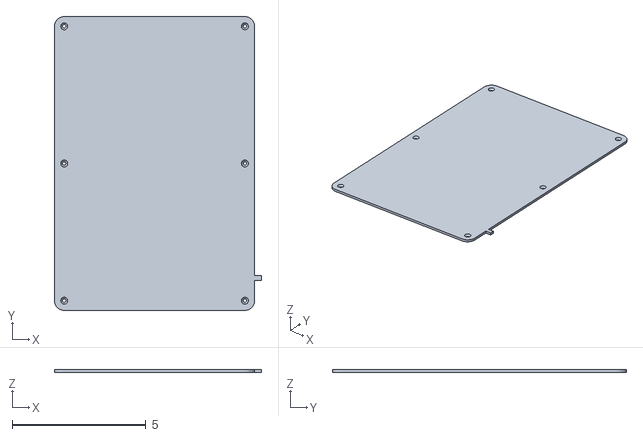
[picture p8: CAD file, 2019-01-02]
MiniB0XX/Original MiniB0XX/LID.stl
7.74 x 11.0 x 0.1

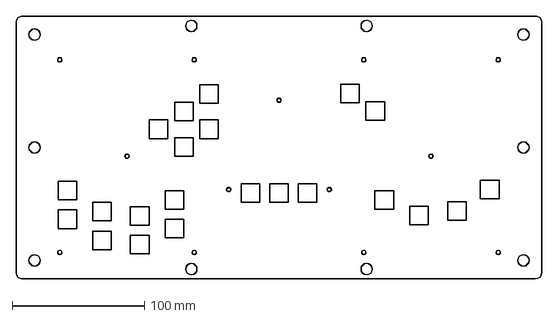
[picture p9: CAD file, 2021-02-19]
LayoutFiles/DXF/GCCMX_SwitchPlate.dxf
397.2 x 198.6 mm

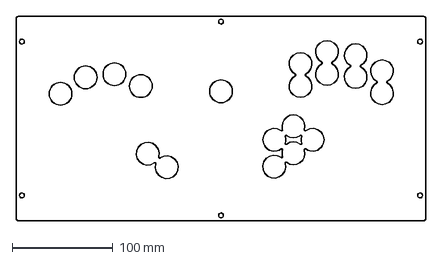
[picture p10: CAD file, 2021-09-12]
LayoutFiles/DXF/Hammond16x8Case/Hammond_LargeCircleCover_20.dxf
406.4 x 203.2 mm

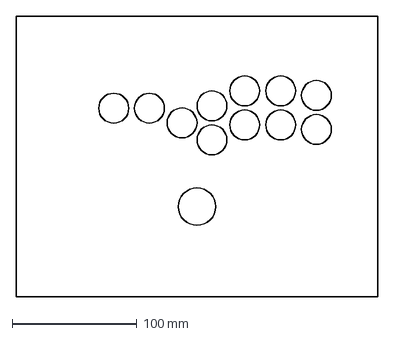
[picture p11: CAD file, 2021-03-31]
LayoutFiles/DXF/Hammond16x8Case/Hitbox/iPadHitbox.dxf
290.0 x 225.0 mm

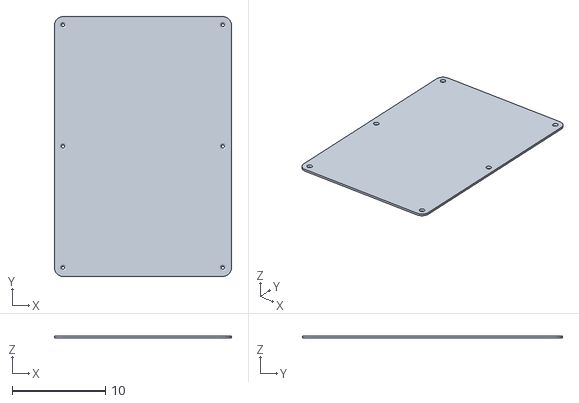
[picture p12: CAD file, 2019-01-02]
MiniB0XX/Detatchable MiniB0XX/Both/DetatchableLID.stl
19.0 x 27.9 x 0.254

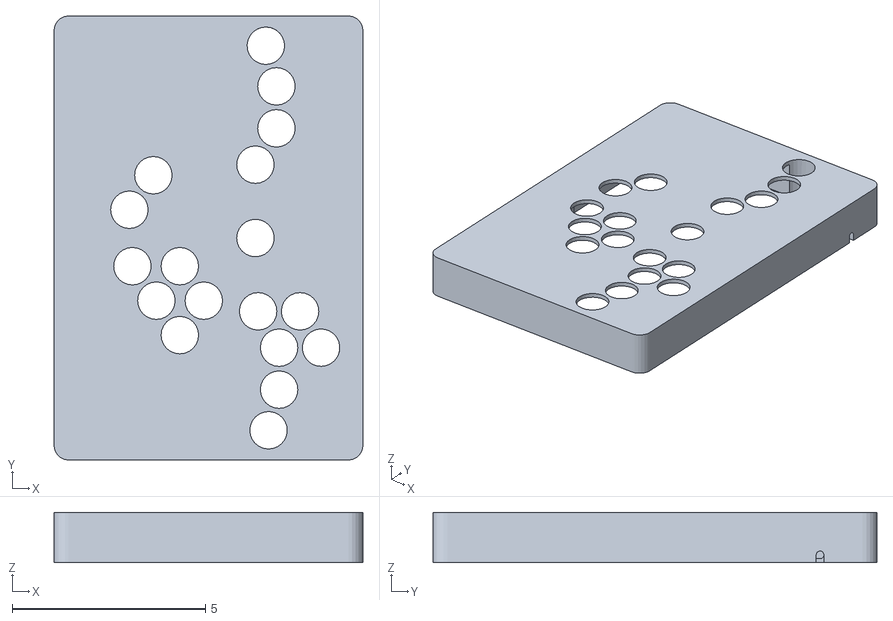
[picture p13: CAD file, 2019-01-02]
MiniB0XX/Original MiniB0XX/B0XX.stl
8.00 x 11.5 x 1.30

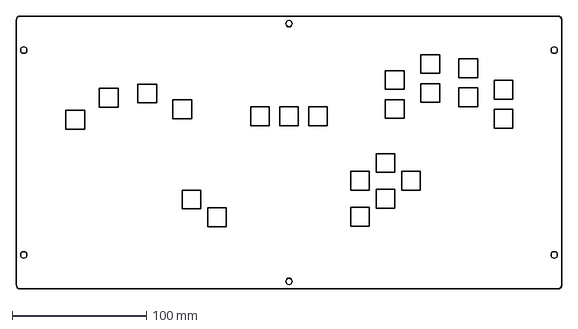
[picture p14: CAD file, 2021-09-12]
LayoutFiles/DXF/Hammond16x8Case/Hammond_SwitchPlate.dxf
406.4 x 203.2 mm

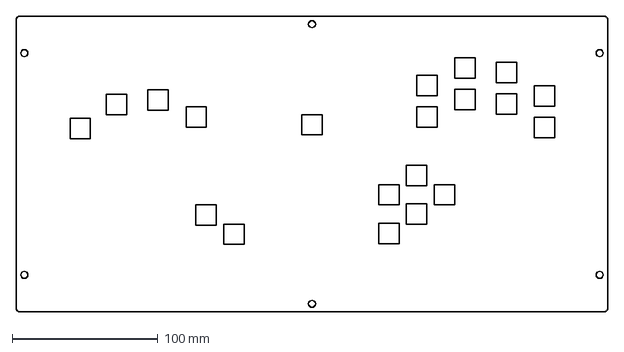
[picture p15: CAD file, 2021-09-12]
LayoutFiles/DXF/Hammond16x8Case/Hammond_SwitchPlate_20.dxf
406.4 x 203.2 mm

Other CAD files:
MiniB0XX/Detatchable MiniB0XX/JustRJ45/DetatchableB0XXJustRJ45.stl
MiniB0XX/Detatchable MiniB0XX/JustUSB/DetatchableB0XXJustUSBFeedthru.stl
MyAluminumB0XX/AcrylicPlate/GuitarHeroB0XX/GuitarHeroB0XX.dwg
MyAluminumB0XX/AcrylicPlate/Standard/Aluminum Acrylic plate v2.dwg
MyAluminumB0XX/Case Modification/GCC holes.dwg
LayoutFiles/DXF/Hammond16x8Case/Hammond_24mm_TopPanel.dxf
LayoutFiles/DXF/Hammond16x8Case/Hammond_26mm_Support.dxf
MiniB0XX/Detatchable MiniB0XX/.ipts/DetatchableB0XX.ipt
MiniB0XX/Detatchable MiniB0XX/.ipts/DetatchableLID.ipt

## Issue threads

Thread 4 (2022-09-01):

Wrong stick coordinates since Slippi 2.5.0

CollaboratingElephant, 2022-09-01:
Device: Leonardo R3 Arduino ATMega32U4 Pro Micro
Host: USB-B to USB-A, DIYGCC_USB
Game: Melee, Slippi 2.5.0
Buttons pressed while plugging in: None
Actions: Pressing modX and various control stick directions

Expected behaviour:
Modx+down producing the Y value of -0,28750,
Modx+left producing the X value of -0,66250
Modx+left+down producing the X value of -0,73750, and Y value of -0,28750

Actual behaviour:
Modx+down produces the Y value of -0,27500
Modx+left produces the X value of -0,65000
Modx+left+down produces the X value of -0,72500, and Y value of -0,27500.

All of this started happening only when Slippi updated to 2.5.0, and Arte suggested it might be because of this pull:

https://github.com/project-slippi/Ishiiruka/pull/356

CollaboratingElephant, 2022-09-02:
The Slippi team reverted the changes that lead to the issue. Problem solved.

Closed 2022-09-02.

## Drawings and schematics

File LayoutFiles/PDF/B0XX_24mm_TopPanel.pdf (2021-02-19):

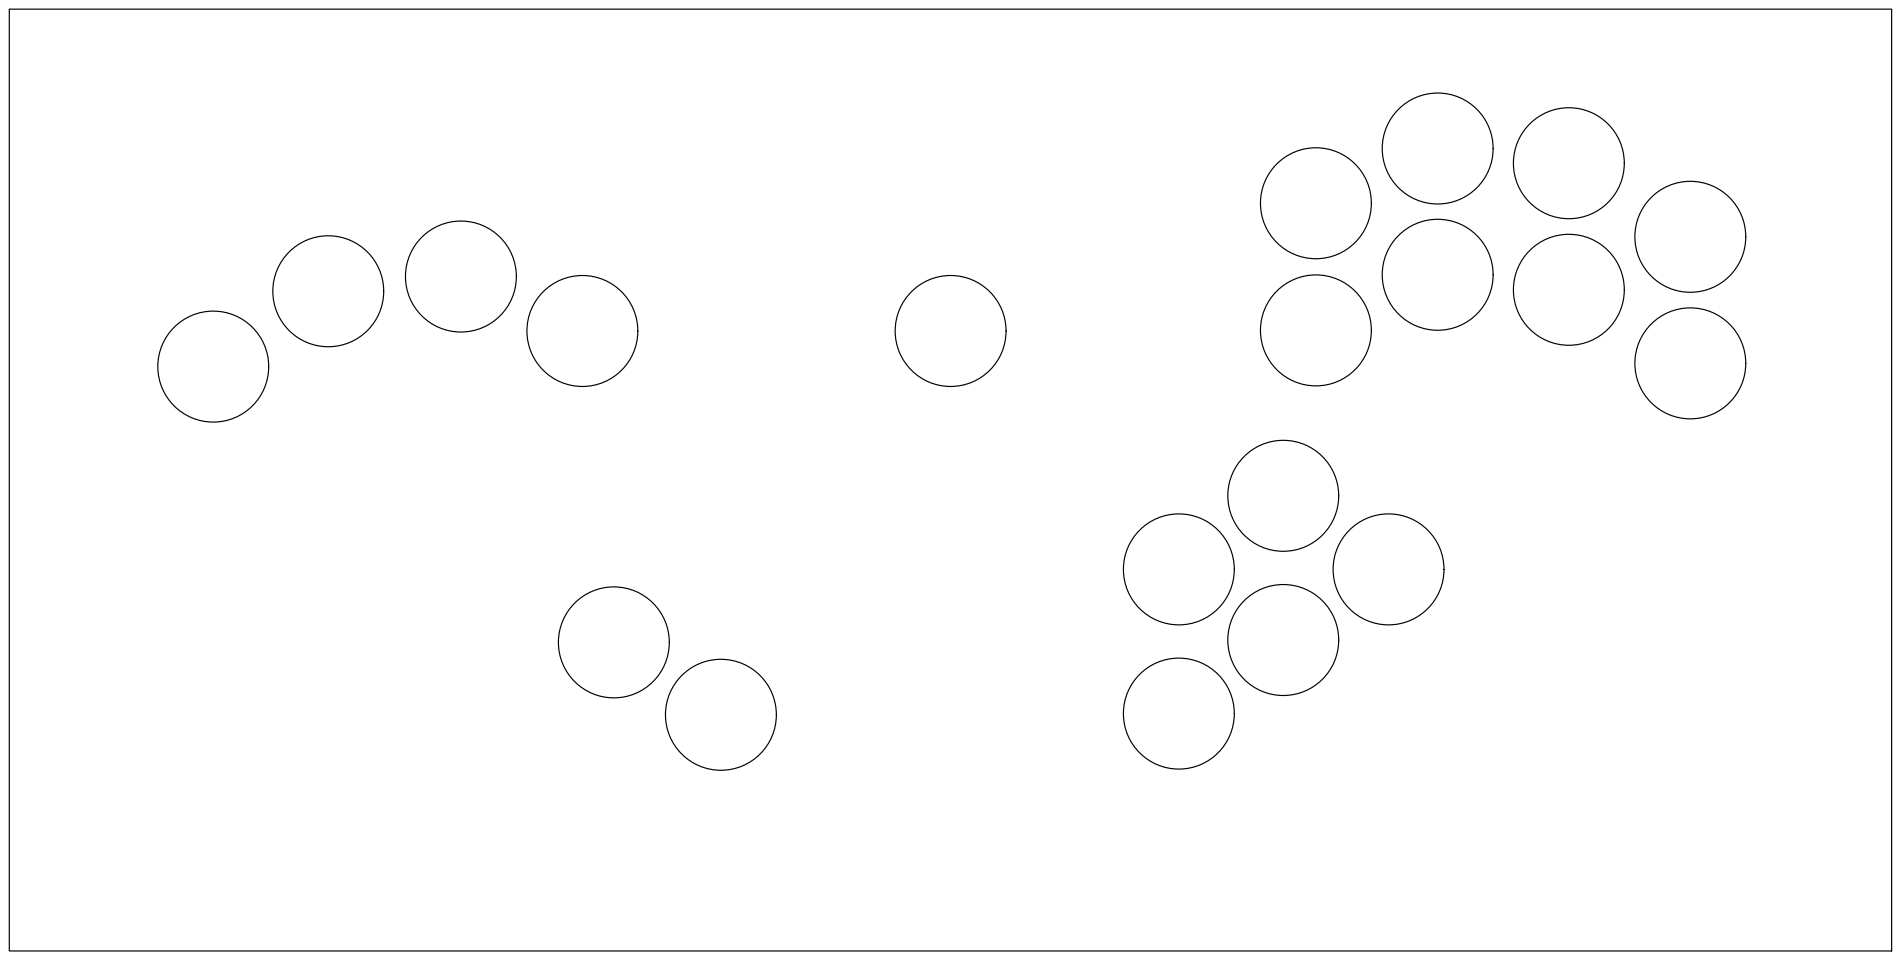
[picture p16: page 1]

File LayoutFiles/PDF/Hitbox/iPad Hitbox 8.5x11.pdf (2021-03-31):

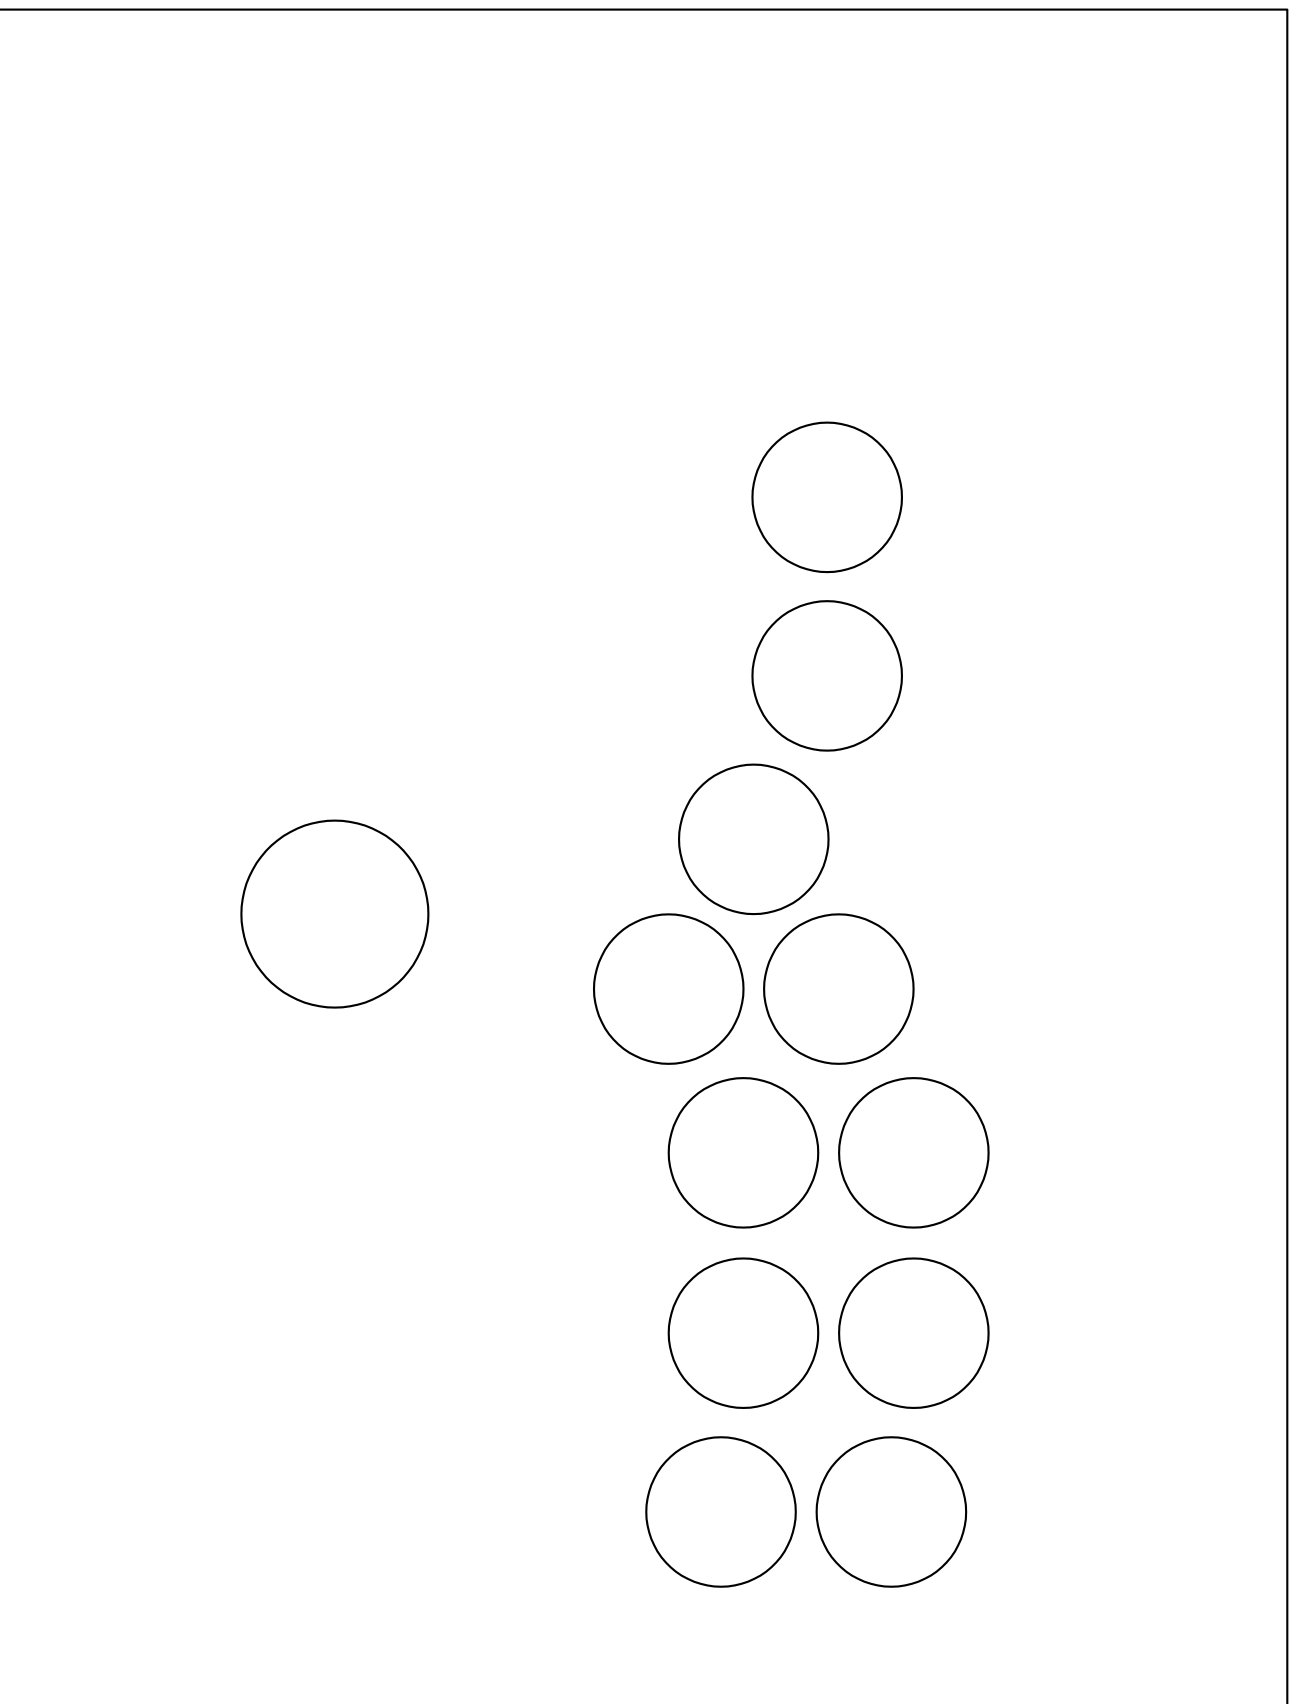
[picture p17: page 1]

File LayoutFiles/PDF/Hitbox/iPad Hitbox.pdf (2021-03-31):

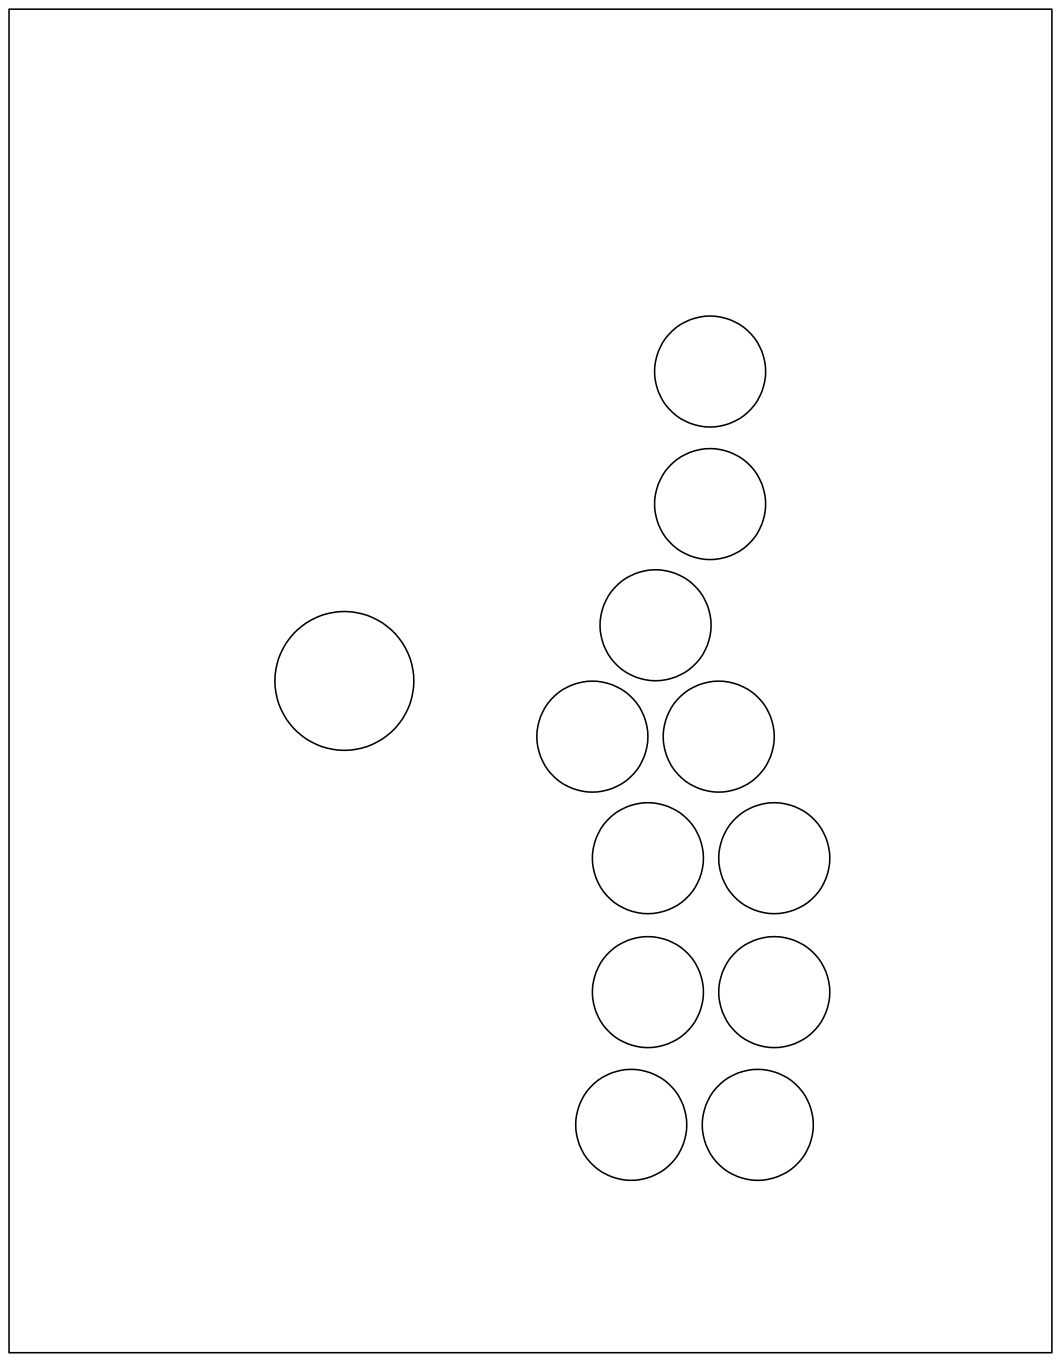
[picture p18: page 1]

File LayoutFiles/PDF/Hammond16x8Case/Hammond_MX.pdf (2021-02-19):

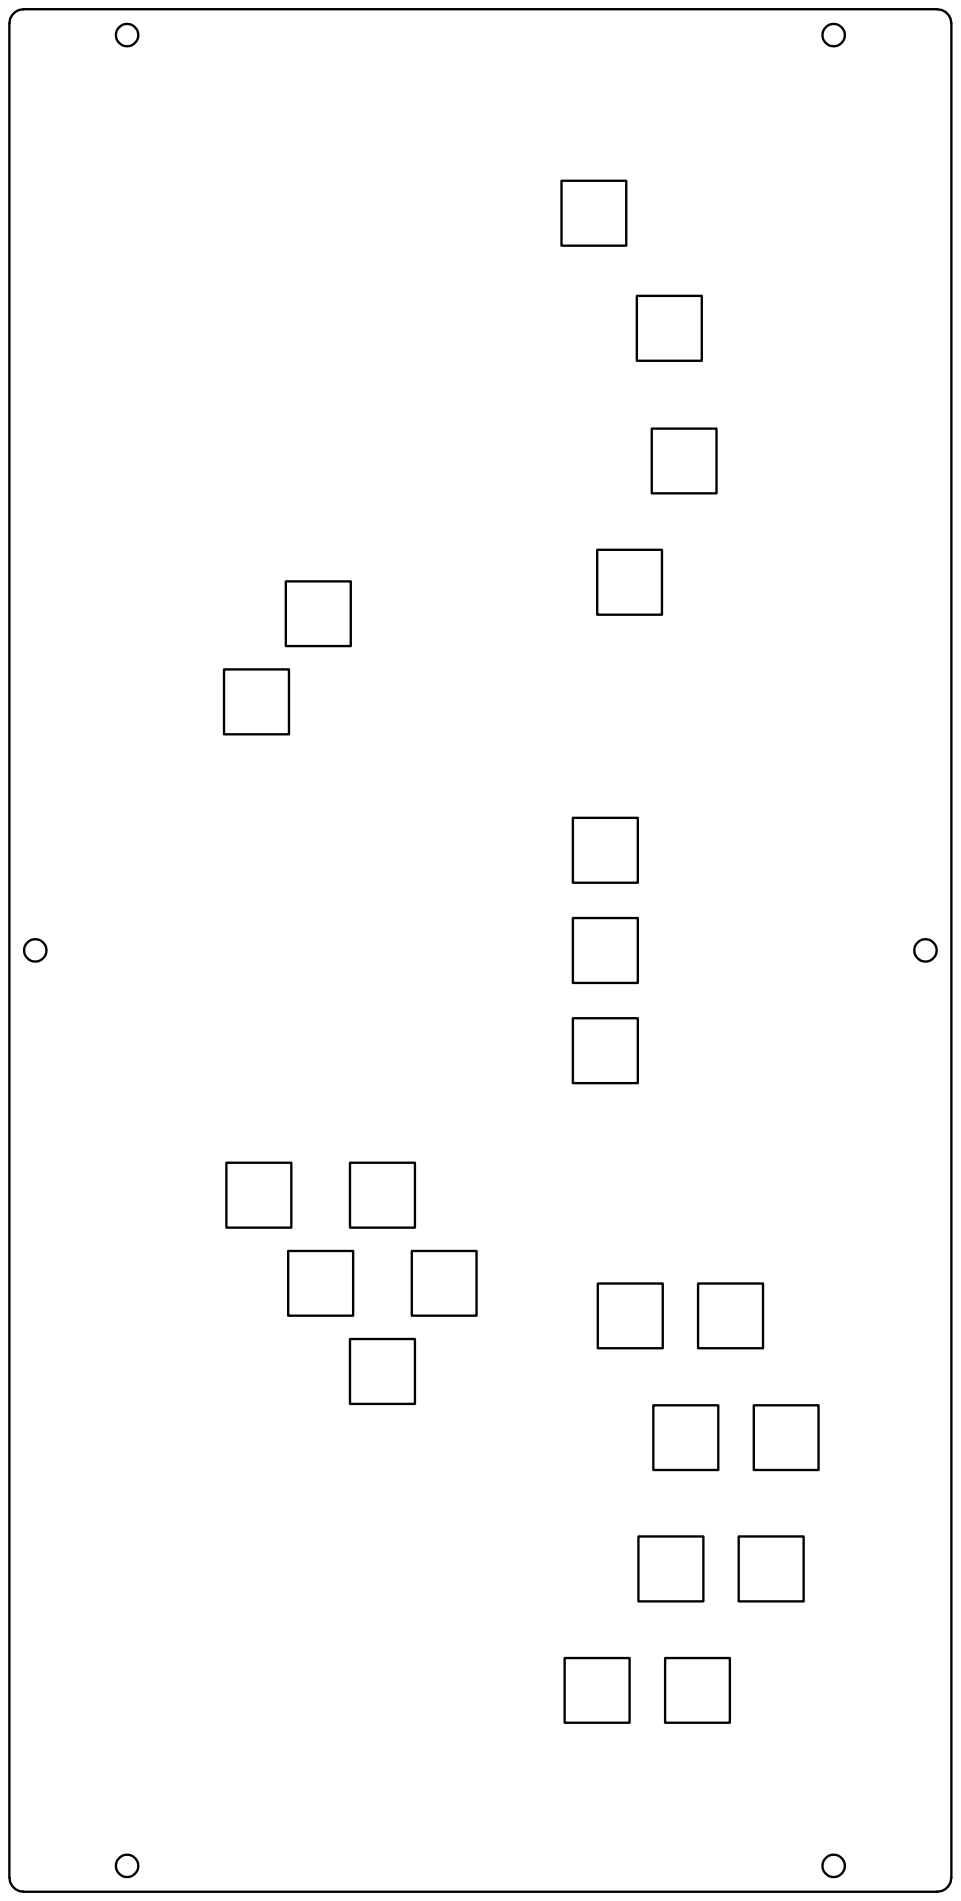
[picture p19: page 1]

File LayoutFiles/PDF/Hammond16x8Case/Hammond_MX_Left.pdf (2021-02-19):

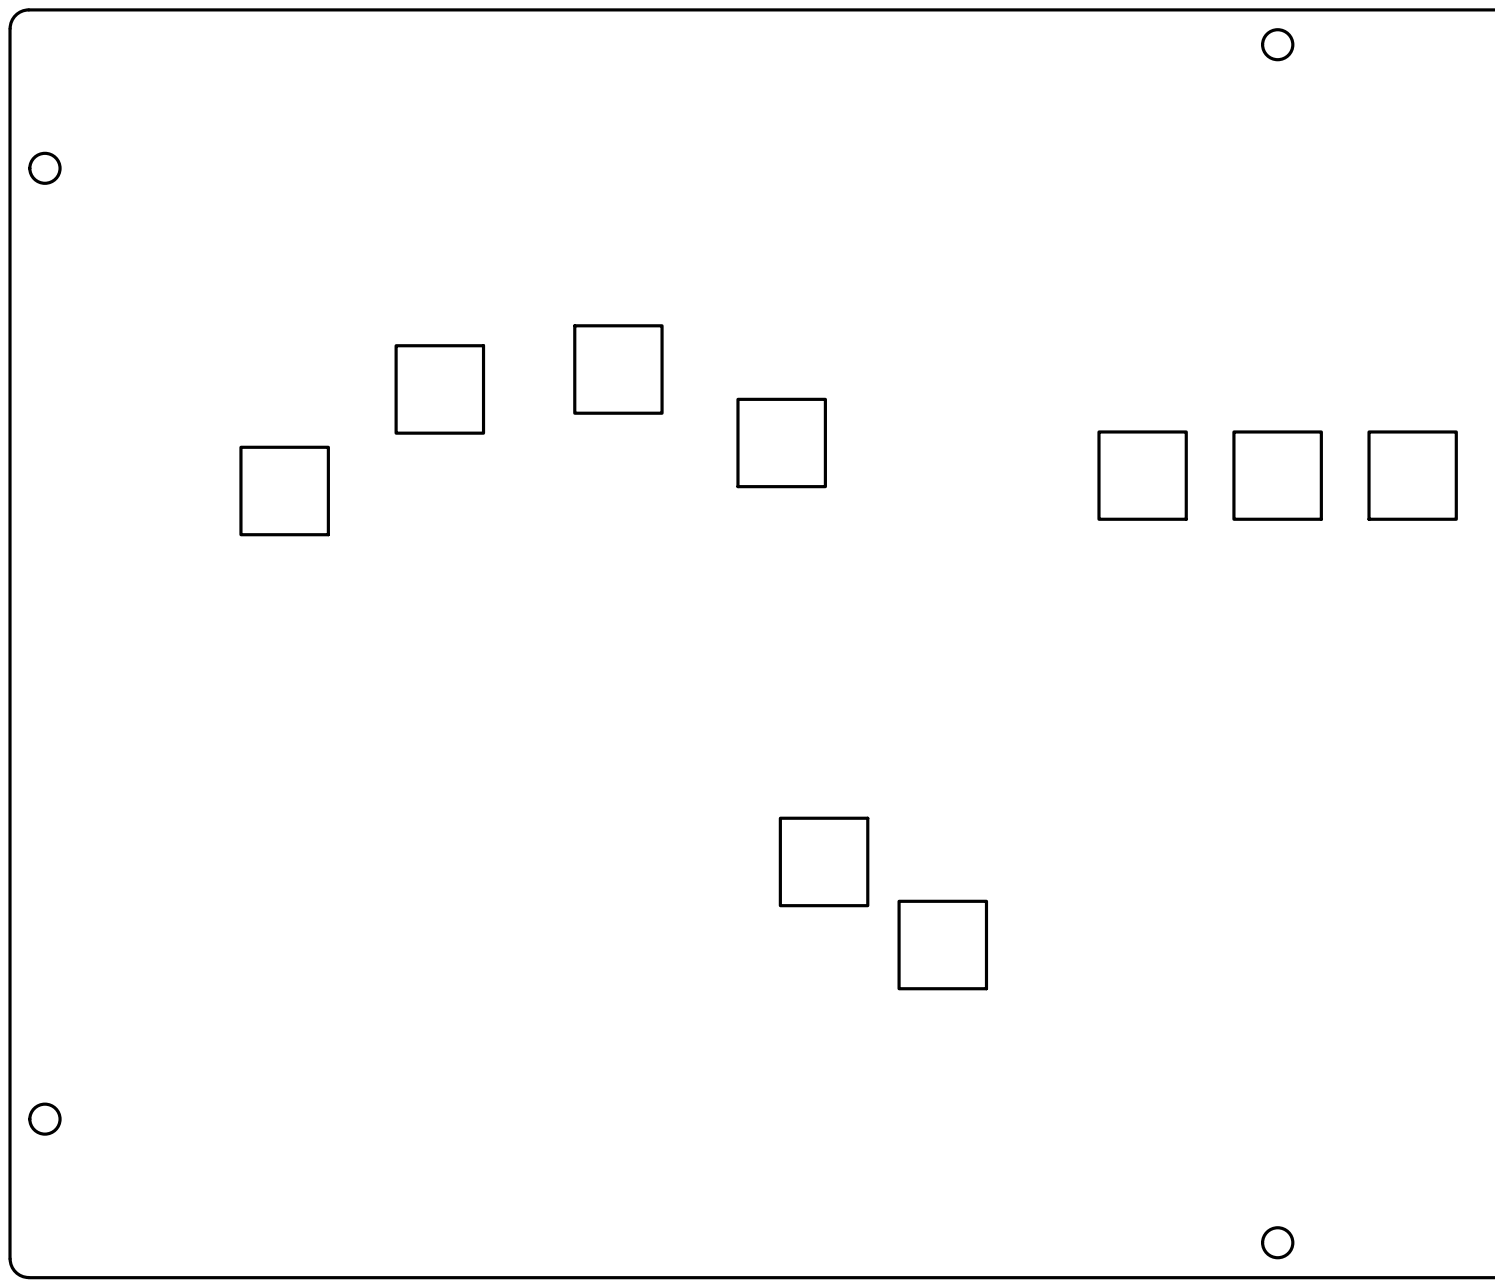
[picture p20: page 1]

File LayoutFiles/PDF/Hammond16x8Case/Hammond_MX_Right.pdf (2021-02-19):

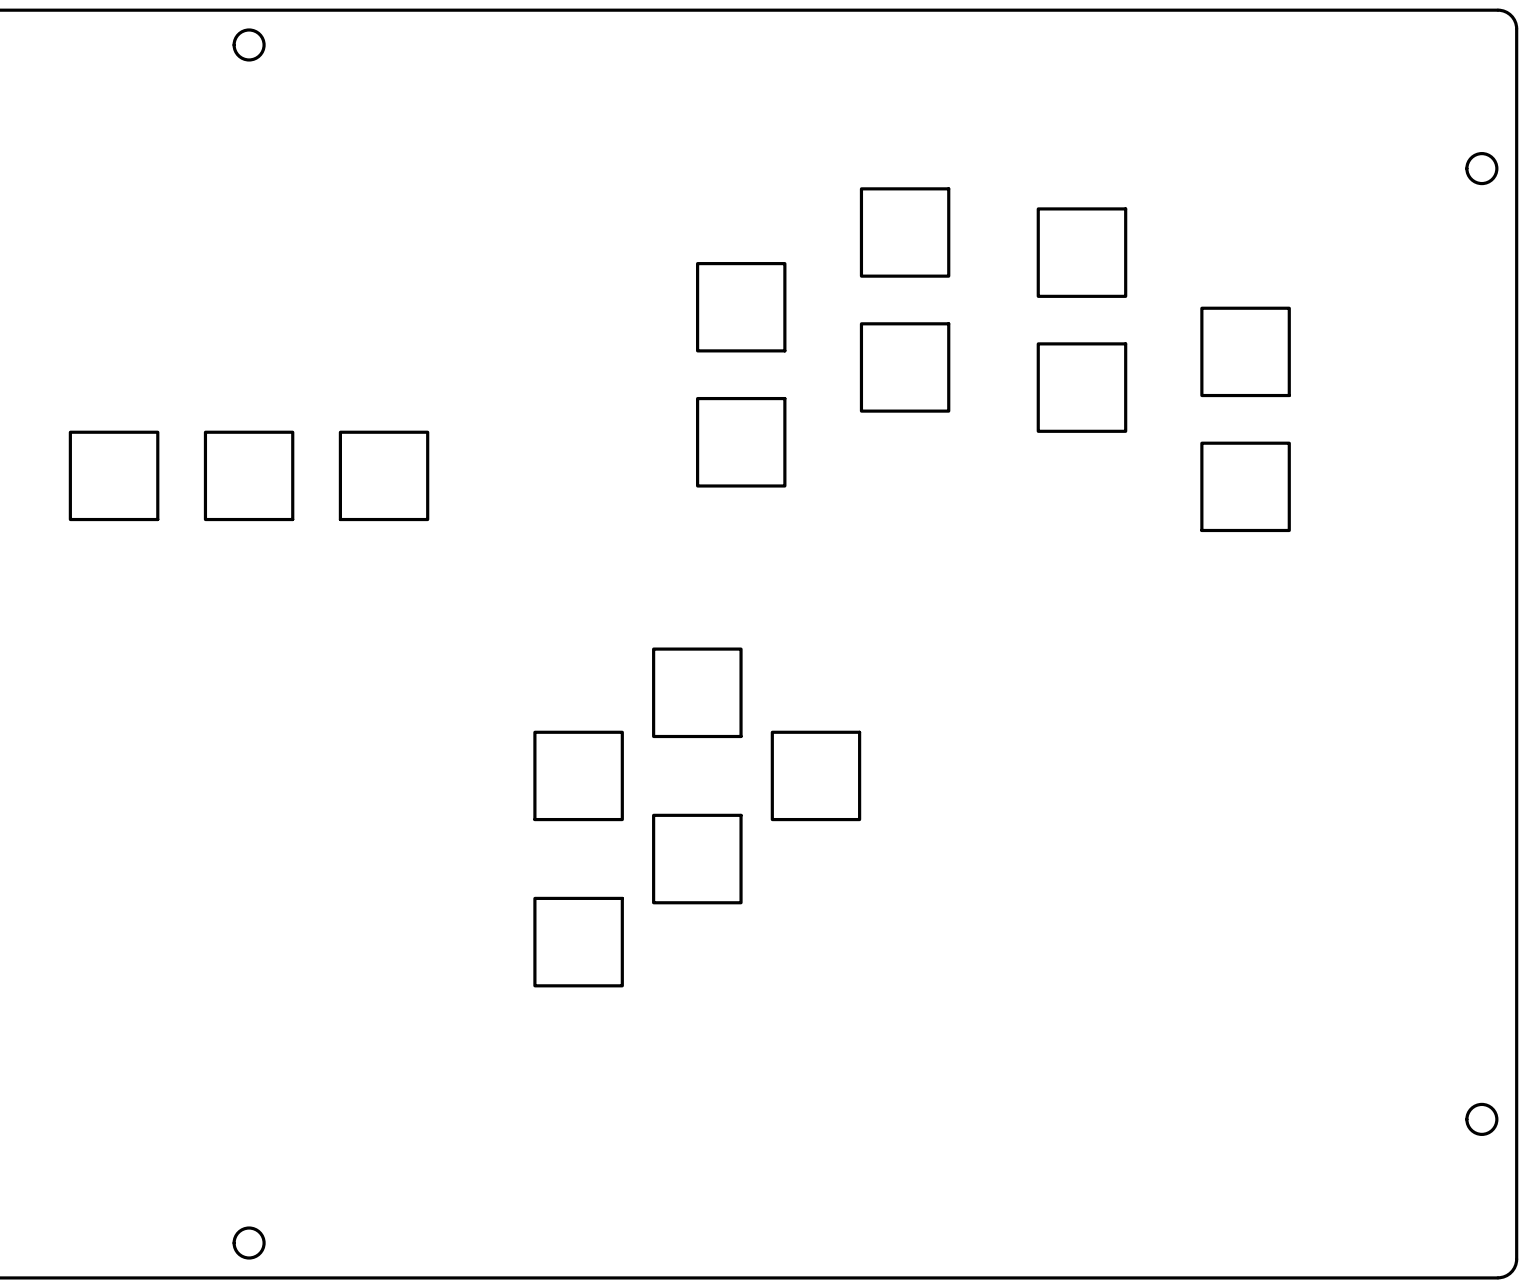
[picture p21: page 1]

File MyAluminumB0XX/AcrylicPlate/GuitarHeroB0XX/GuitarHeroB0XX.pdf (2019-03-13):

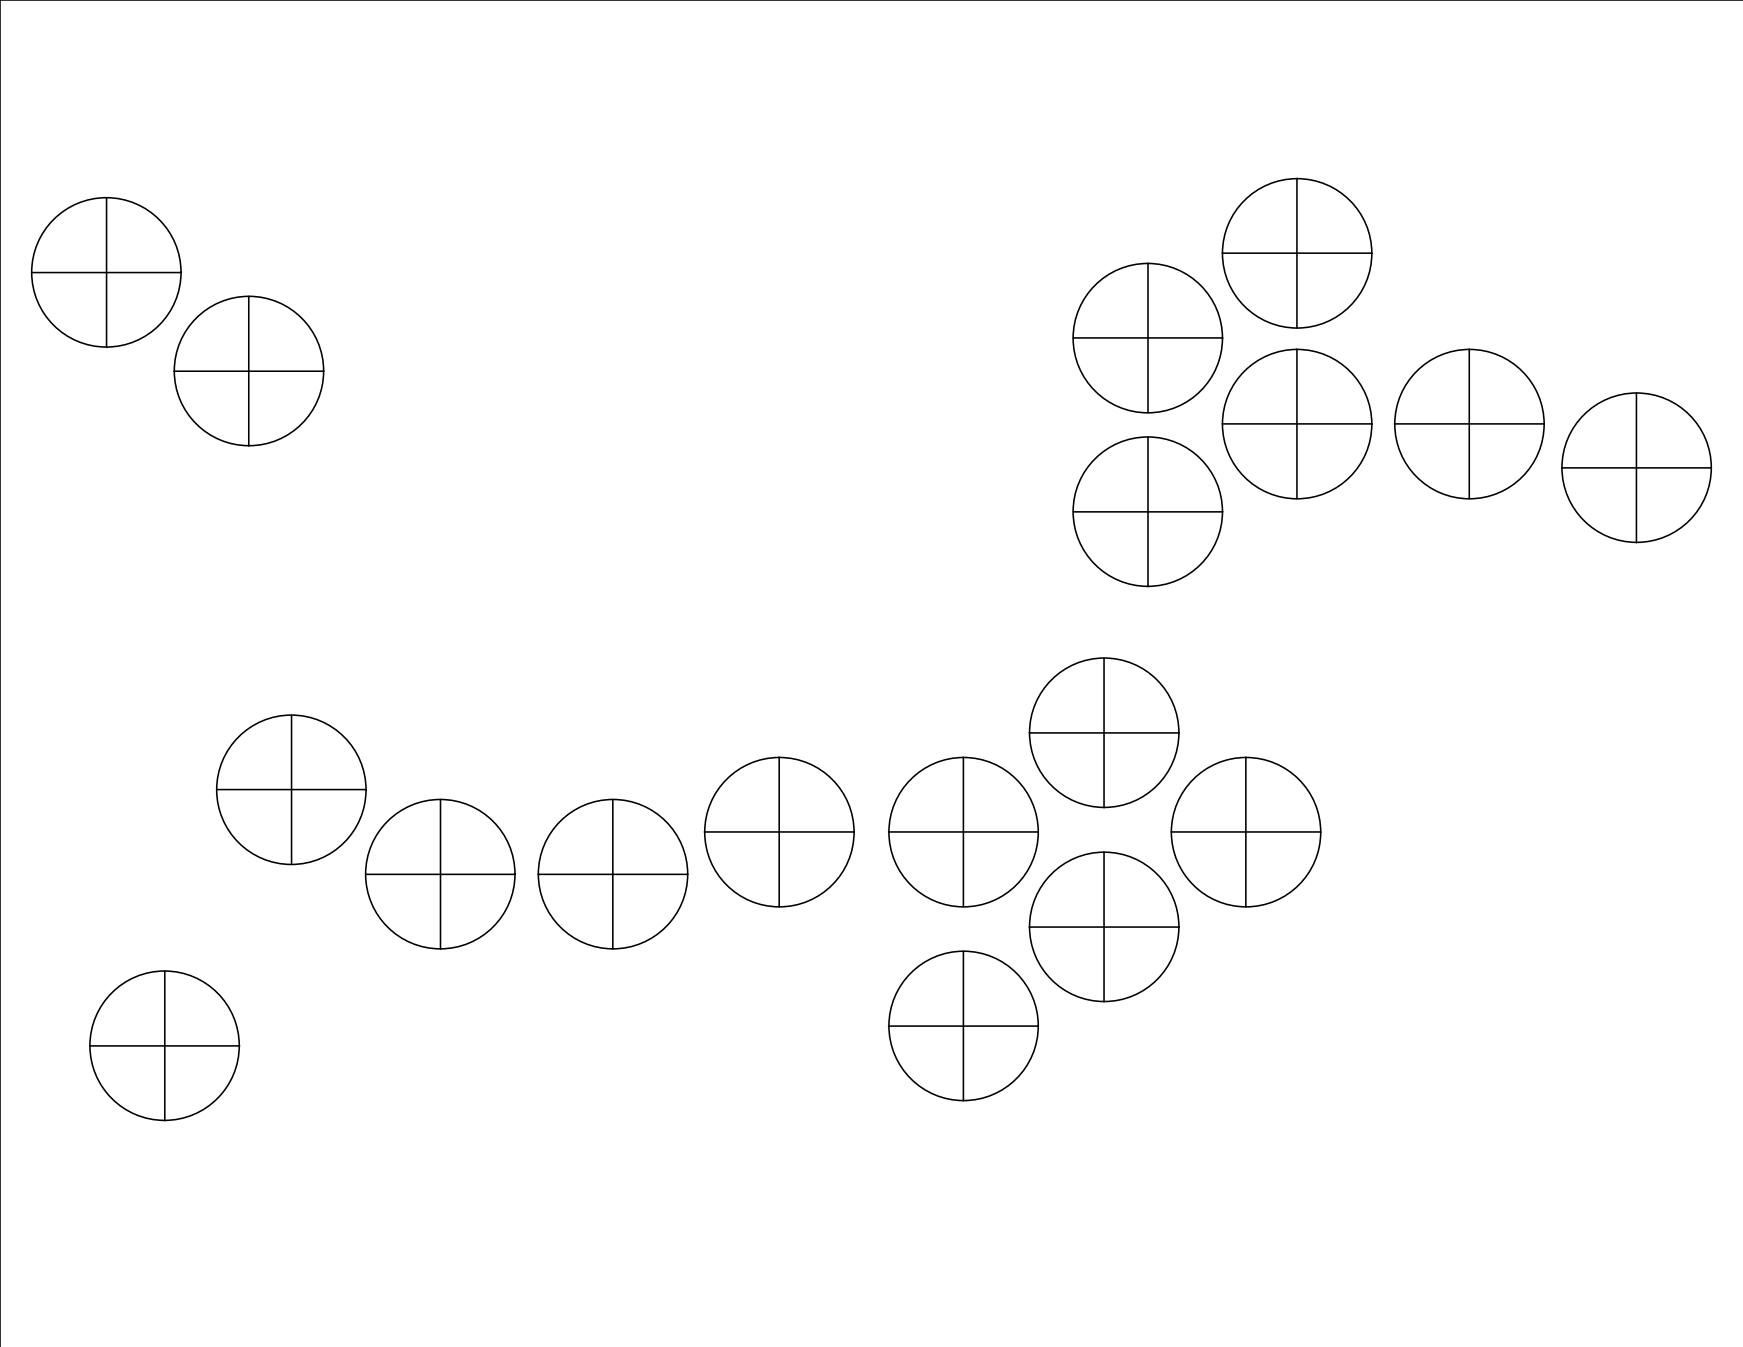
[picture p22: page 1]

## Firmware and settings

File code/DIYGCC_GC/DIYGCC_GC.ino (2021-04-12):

/*
  DIYGCC GameCube Only v1.209 by Crane.
  This code utilizes
    Nicohood's Nintendo library

  This code is for DIY controllers using Arduinos with 8 bit AVR microcontrollers
  running at 16 MHz that do not support native usb (Mega2560, Nano, etc)
*/
#include "Nintendo.h"

bool isLightShieldButtons = true; //set to false to use modX+L for lightshield
bool UseNewModVertical = true;

uint8_t fTwoIPNoReactivate(bool isLOW, bool isHIGH, bool& wasLOW, bool& wasHIGH, bool& lockLOW, bool& lockHIGH);
uint8_t fTwoIP(bool isLOW, bool isHIGH, bool& wasLOW, bool& wasHIGH);
uint8_t fNeutral(bool isLOW, bool isHIGH);

// Change the number inside the parentheses to whichever pin you have your data line plugged into.
CGamecubeConsole GamecubeConsole(A5);
Gamecube_Data_t d = defaultGamecubeData;

enum game
{
  Melee,
  PM,
  Ultimate
};

enum SOCD
{
  Neutral,
  TwoIP,
  TwoIPNoReactivate
};

bool wasLEFT = false;
bool wasRIGHT = false;
bool wasUP = false;
bool wasDOWN = false;

bool wasCLEFT = false;
bool wasCRIGHT = false;
bool wasCUP = false;
bool wasCDOWN = false;

bool lockLEFT = false;
bool lockRIGHT = false;
bool lockUP = false;
bool lockDOWN = false;

bool lockCLEFT = false;
bool lockCRIGHT = false;
bool lockCUP = false;
bool lockCDOWN = false;

// This is the mode that will occur when you plug in while holding down nothing.
// Change it if you want to.
game currentGame = Melee;
SOCD currentSOCD = TwoIPNoReactivate;

bool LatencyFix = false;

// Here are your pin assignments. Change the number after the equals sign to wherever each button is plugged into.
const int L = 16;
const int LEFT = 1;
const int DOWN = 0;
const int RIGHT = 4;
const int MODX = 5;
const int MODY = 6;

const int START = 7;
const int B = A2;
const int X = A1;
const int Z = A0;
const int UP = 13;
const int R = A4;
const int Y = A3;

const int CDOWN = 12;
const int A = 15;
const int CRIGHT = 14;
const int CLEFT = 9;
const int CUP = 8;

const int LIGHTSHIELD = 11;
const int MIDSHIELD = 10;

//const int DPADSWITCH = XX;

const uint8_t minValue = 28;
const uint8_t maxValue = 228;

void setup()
{
  pinMode(L, INPUT_PULLUP);
  pinMode(LEFT, INPUT_PULLUP);
  pinMode(DOWN, INPUT_PULLUP);
  pinMode(RIGHT, INPUT_PULLUP);
  pinMode(MODX, INPUT_PULLUP);
  pinMode(MODY, INPUT_PULLUP);
  pinMode(START, INPUT_PULLUP);
  pinMode(B, INPUT_PULLUP);
  pinMode(X, INPUT_PULLUP);
  pinMode(Z, INPUT_PULLUP);
  pinMode(UP, INPUT_PULLUP);
  pinMode(R, INPUT_PULLUP);
  pinMode(Y, INPUT_PULLUP);
  pinMode(CDOWN, INPUT_PULLUP);
  pinMode(A, INPUT_PULLUP);
  pinMode(CRIGHT, INPUT_PULLUP);
  pinMode(CLEFT, INPUT_PULLUP);
  pinMode(CUP, INPUT_PULLUP);
  if (isLightShieldButtons) {
    pinMode(LIGHTSHIELD, INPUT_PULLUP);
    pinMode(MIDSHIELD, INPUT_PULLUP);
  }
  //pinMode(DPADSWITCH, INPUT_PULLUP);

  // Here are the settings for a second mode. By default, holding B while plugging in switches
  // to Ultimate, with 2ip no reactivation. Change any of these you want to.
  if (digitalRead(B) == LOW)
  {
    currentGame = Ultimate;
    currentSOCD = TwoIP;
  }

  // Here are the settings for a third mode. By default, holding X while plugging in switches
  // to PM, with 2ip no reactivation. Change any of these you want to.
  if (digitalRead(X) == LOW)
  {
    currentGame = PM;
    currentSOCD = TwoIPNoReactivate;
  }

  // Hold Start on plugin to enable the latency fix for Melee on GC/Wii
  if (digitalRead(START) == LOW)
  {
    LatencyFix = true;
  }
}

void loop()
{
  bool isL          = (digitalRead(L) == LOW);
  bool isLEFT       = (digitalRead(LEFT) == LOW);
  bool isDOWN       = (digitalRead(DOWN) == LOW);
  bool isRIGHT      = (digitalRead(RIGHT) == LOW);
  bool isMODX       = (digitalRead(MODX) == LOW);
  bool isMODY       = (digitalRead(MODY) == LOW);
  bool isSTART      = (digitalRead(START) == LOW);
  bool isB          = (digitalRead(B) == LOW);
  bool isX          = (digitalRead(X) == LOW);
  bool isZ          = (digitalRead(Z) == LOW);
  bool isUP         = (digitalRead(UP) == LOW);
  bool isR          = (digitalRead(R) == LOW);
  bool isY          = (digitalRead(Y) == LOW);
  bool isCDOWN      = (digitalRead(CDOWN) == LOW);
  bool isA          = (digitalRead(A) == LOW);
  bool isCRIGHT     = (digitalRead(CRIGHT) == LOW);
  bool isCLEFT      = (digitalRead(CLEFT) == LOW);
  bool isCUP        = (digitalRead(CUP) == LOW);
  bool isLIGHTSHIELD     = (digitalRead(LIGHTSHIELD) == LOW);
  bool isMIDSHIELD     = (digitalRead(MIDSHIELD) == LOW);
  //bool isDPADSWITCH = (digitalRead(DPADSWITCH) == LOW);

  bool isDPADUP = false;
  bool isDPADDOWN = false;
  bool isDPADLEFT = false;
  bool isDPADRIGHT = false;

  uint8_t controlX = 128;
  uint8_t controlY = 128;
  uint8_t cstickX = 128;
  uint8_t cstickY = 128;
  uint8_t RLight = 0;
  uint8_t LLight = 0;

  int8_t positionX = 0;
  int8_t positionY = 0;
  int8_t positionCX = 0;
  int8_t positionCY = 0;

  bool HORIZONTAL = false;
  bool VERTICAL = false;
  bool DIAGONAL = false;

  /********* SOCD *********/
  if (currentSOCD == TwoIPNoReactivate) {
    controlX = fTwoIPNoReactivate(isLEFT, isRIGHT, wasLEFT, wasRIGHT, lockLEFT, lockRIGHT);
    controlY = fTwoIPNoReactivate(isDOWN, isUP, wasDOWN, wasUP, lockDOWN, lockUP);
    cstickX = fTwoIPNoReactivate(isCLEFT, isCRIGHT, wasCLEFT, wasCRIGHT, lockCLEFT, lockCRIGHT);
    cstickY = fTwoIPNoReactivate(isCDOWN, isCUP, wasCDOWN, wasCUP, lockCDOWN, lockCUP);
  }

  if (currentSOCD == TwoIP){
    controlX = fTwoIP(isLEFT, isRIGHT, wasLEFT, wasRIGHT);
    controlY = fTwoIP(isDOWN, isUP, wasDOWN, wasUP);
    cstickX = fTwoIP(isCLEFT, isCRIGHT, wasCLEFT, wasCRIGHT);
    cstickY = fTwoIP(isCDOWN, isCUP, wasCDOWN, wasCUP);
  }

  if (currentSOCD == Neutral) {
    controlX = fNeutral(isLEFT, isRIGHT);
    controlY = fNeutral(isDOWN, isUP);
    cstickX = fNeutral(isCLEFT, isCRIGHT);
    cstickY = fNeutral(isCDOWN, isCUP);
  }

  if (controlX != 128) {
    HORIZONTAL = true;
    if (controlX == minValue) positionX = -1;
    else positionX = 1;
  }
  if (controlY != 128) {
    VERTICAL = true;
    if (controlY == minValue) positionY = -1;
    else positionY = 1;
  }
  if (HORIZONTAL && VERTICAL) DIAGONAL = true;

  if (cstickX != 128) {
    if (cstickX == minValue) positionCX = -1;
    else positionCX = 1;
  }
  if (cstickY != 128) {
    if (cstickY == minValue) positionCY = -1;
    else positionCY = 1;
  }
  /********* Modifiers *********/

  if (isMODX) {
    if (HORIZONTAL) {
      if (currentGame == Melee) controlX = 128 + (positionX * 53);
      if (currentGame == Ultimate) controlX = 128 + (positionX * 40);
      if (currentGame == PM) controlX = 128 + (positionX * 70);
    }
    if (VERTICAL) {
      if (currentGame == Melee) {
        if (UseNewModVertical)
          controlY = 128 + (positionY * 23);
        else
          controlY = 128 + (positionY * 52);
      }
      if (currentGame == Ultimate) controlY = 128 + (positionY * 49);
      if (currentGame == PM) controlY = 128 + (positionY * 60);
    }

    if (isB) {
      if (currentGame == Melee) controlX = 128 + (positionX * 53);
      if (currentGame == Ultimate) {
        controlX = 128 + (positionX * 47);
        controlY = 128 + (positionY * 41);
      }
    }
    if (positionCX != 0){
      cstickX = 128 + (positionCX * 65);
      cstickY = 128 + (positionY * 23);
    }

    if (DIAGONAL) {
      if (currentGame == Melee) {
        controlX = 128 + (positionX * 59);
        controlY = 128 + (positionY * 23);
      }
      if (currentGame == Ultimate) {
        controlX = 128 + (positionX * 40);
        controlY = 128 + (positionY * 26);
        if (isB) controlX = 128 + (positionX * 53);
      }
      if (currentGame == PM) {
        controlX = 128 + (positionX * 70);
        controlY = 128 + (positionY * 34);
      }

      if (isCUP) {
        if (currentGame == Melee) {
          controlX = 128 + (positionX * 49);
          controlY = 128 + (positionY * 35);
        }
        if (currentGame == Ultimate) {
          controlX = 128 + (positionX * 71);
          controlY = 128 + (positionY * 35);
        }
        if (currentGame == PM) {
          controlX = 128 + (positionX * 77);
          controlY = 128 + (positionY * 55);
        }
      }

      if (isCDOWN) {
        if (currentGame == Melee) {
          controlX = 128 + (positionX * 49);
          controlY = 128 + (positionY * 24);
        }
        if (currentGame == Ultimate) {
          controlX = 128 + (positionX * 61);
          controlY = 128 + (positionY * 49);
        }
        if (currentGame == PM) {
          controlX = 128 + (positionX * 82);
          controlY = 128 + (positionY * 32);
        }
      }

      if (isCLEFT) {
        if (currentGame == Melee) {
          controlX = 128 + (positionX * 52);
          controlY = 128 + (positionY * 31);
        }
        if (currentGame == Ultimate) {
          controlX = 128 + (positionX * 66);
          controlY = 128 + (positionY * 42);
        }
        if (currentGame == PM) {
          controlX = 128 + (positionX * 84);
          controlY = 128 + (positionY * 50);
        }
      }

      if (isCRIGHT) {
        if (currentGame == Melee) {
          controlX = 128 + (positionX * 51);
          controlY = 128 + (positionY * 43);
        }
        if (currentGame == Ultimate) {
          controlX = 128 + (positionX * 75);
          controlY = 128 + (positionY * 27);
        }
        if (currentGame == PM) {
          controlX = 128 + (positionX * 72);
          controlY = 128 + (positionY * 61);
        }
      }
    }
  }

  if (isMODY) {
    if (HORIZONTAL) {
      if (currentGame == Melee) controlX = 128 + (positionX * 27);
      if (currentGame == Ultimate) controlX = 128 + (positionX * 27);
      if (currentGame == PM) controlX = 128 + (positionX * 28);
    }
    if (VERTICAL) {
      if (currentGame == Melee) controlY = 128 + (positionY * 59);
      if (currentGame == Ultimate) controlY = 128 + (positionY * 51);
      if (currentGame == PM) controlY = 128 + (positionY * 34);
    }

    if (isB) {
      if (currentGame == Melee) controlX = 128 + (positionX * 80);
      if (currentGame == Ultimate) {
        controlX = 128 + (positionX * 41);
        controlY = 128 + (positionY * 61);
      }
      if (currentGame == PM) controlX = 128 + (positionX * 59);
    }

    if (DIAGONAL) {
      if (currentGame == Melee) {
        controlX = 128 + (positionX * 23);
        controlY = 128 + (positionY * 59);
      }
      if (currentGame == Ultimate) {
        controlX = 128 + (positionX * 38);
        controlY = 128 + (positionY * 49);
      }
      if (currentGame == PM) {
        controlX = 128 + (positionX * 28);
        controlY = 128 + (positionY * 58);
      }

      if (isCUP) {
        if (currentGame == Melee) {
          controlX = 128 + (positionX * 45);
          controlY = 128 + (positionY * 63);
        }
        if (currentGame == Ultimate) {
          controlX = 128 + (positionX * 35);
          controlY = 128 + (positionY * 71);
        }
        if (currentGame == PM) {
          controlX = 128 + (positionX * 55);
          controlY = 128 + (positionY * 77);
        }
      }

      if (isCDOWN) {
        if (currentGame == Melee) {
          controlX = 128 + (positionX * 28);
          controlY = 128 + (positionY * 57);
        }
        if (currentGame == Ultimate) {
          controlX = 128 + (positionX * 49);
          controlY = 128 + (positionY * 61);
        }
        if (currentGame == PM) {
          controlX = 128 + (positionX * 32);
          controlY = 128 + (positionY * 82);
        }
      }

      if (isCLEFT) {
        if (currentGame == Melee) {
          controlX = 128 + (positionX * 34);
          controlY = 128 + (positionY * 57);
        }
        if (currentGame == Ultimate) {
          controlX = 128 + (positionX * 42);
          controlY = 128 + (positionY * 66);
        }
        if (currentGame == PM) {
          controlX = 128 + (positionX * 50);
          controlY = 128 + (positionY * 84);
        }
      }

      if (isCRIGHT) {
        if (currentGame == Melee) {
          controlX = 128 + (positionX * 47);
          controlY = 128 + (positionY * 57);
        }
        if (currentGame == Ultimate) {
          controlX = 128 + (positionX * 27);
          controlY = 128 + (positionY * 75);
        }
        if (currentGame == PM) {
          controlX = 128 + (positionX * 62);
          controlY = 128 + (positionY * 72);
        }
      }
    }
  }

  if (isLEFT && isRIGHT && !VERTICAL)
    controlX = 128 + (positionX * 100);


  if (isLightShieldButtons && (currentGame == Melee)) {
    if (isLIGHTSHIELD || isMIDSHIELD) {
      if (isLIGHTSHIELD) RLight = 80;
      if (isMIDSHIELD) RLight = 125;

      if (HORIZONTAL && (positionY == -1)) {
        controlX = 128 + (positionX * 57);
        controlY = 128 - 55;
      }

      if (isMODX) {
        if (HORIZONTAL) {
          if (currentGame == Ultimate)
            controlX = 128 + (positionX * 51);
          if (currentGame == Melee)
            controlX = 128 + (positionX * 51);
          if (currentGame == PM)
            controlX = 128 + (positionX * 48);
        }

        if (VERTICAL) {
          if (currentGame == Ultimate)
            controlY = 128 + (positionY * 51);
          if (currentGame == Melee)
            controlY = 128 + (positionY * 43);
          if (currentGame == PM)
            controlY = 128 + (positionY * 48);
        }

        if (DIAGONAL)
          if (currentGame == Melee) controlX = 128 + (positionX * 43);

      }
    }
  }

  if (isL) {
    LLight = 140;
    if (HORIZONTAL) controlX = 128 + (positionX * 100);
    if (VERTICAL) controlY = 128 + (positionY * 100);
    if (HORIZONTAL && (positionY == 1)) {
      if (currentGame == Melee){
        controlX = 128 + (positionX * 43);
        controlY = 128 + 43;
      }
      if (currentGame == PM) {
        controlX = 128 + (positionX * 67);
        controlY = 128 + 67;
      }
    }
    if (HORIZONTAL && (positionY == -1)) {
      controlX = 128 + (positionX * 57);
      if (currentGame == Melee) controlY = 128 - 55;
      else {controlX = 128 + (positionX * 100); controlY = minValue;}
    }
    if ((currentGame == Melee) && (isMODX || isMODY)) {
      if (!isLightShieldButtons) {
        if (!(isMODX && isMODY)) {
          isL = false;
          LLight = 80;
        }
      }

      if (DIAGONAL) {
        if (isMODX) {
          controlX = 128 + (positionX * 51);
          controlY = 128 + (positionY * 30);
        }
        if (isMODY) {
          controlX = 128 + (positionX * 40);
          controlY = 128 + (positionY * 68);
        }
      }
    }
  }

  if (isR) {
    RLight = 140;
    if (HORIZONTAL) {
      if (currentGame == Ultimate)
        controlX = 128 + (positionX * 51);
      if (currentGame == Melee)
        controlX = 128 + (positionX * 51);
      if (currentGame == PM)
        controlX = 128 + (positionX * 48);
    }
    if (VERTICAL) {
      if (currentGame == Ultimate)
        controlY = 128 + (positionY * 51);
      if (currentGame == Melee)
        controlY = 128 + (positionY * 43);
      if (currentGame == PM)
        controlY = 128 + (positionY * 48);
    }
    if (DIAGONAL) {
      if (currentGame == Melee) controlX = 128 + (positionX * 43);
      if (isMODX) {
        if (currentGame == Melee){
          controlX = 128 + (positionX * 51);
          controlY = 128 + (positionY * 30);
        }
        if (currentGame == PM){
          controlX = 128 + (positionX * 68);
          controlY = 128 + (positionY * 40);
        }
      }
      if (isMODY) {
        controlX = 128 + (positionX * 40);
        controlY = 128 + (positionY * 68);
      }
    }
  }

  /********* DPAD *********/
  if (isMODX && isMODY) {
    cstickX = 128;
    cstickY = 128;
    if (isCUP) isDPADUP = true;
    if (isCDOWN) isDPADDOWN = true;
    if (isCLEFT) isDPADLEFT = true;
    if (isCRIGHT) isDPADRIGHT = true;
  }

  /********* GC Report *********/
  d.report.l = isL;
  d.report.start = isSTART;
  d.report.b = isB;
  d.report.x = isX;
  d.report.z = isZ;
  d.report.r = isR;
  d.report.y = isY;
  d.report.a = isA;
  d.report.dup = isDPADUP;
  d.report.ddown = isDPADDOWN;
  d.report.dleft = isDPADLEFT;
  d.report.dright = isDPADRIGHT;

  d.report.xAxis = controlX;
  d.report.yAxis = controlY;
  d.report.cxAxis = cstickX;
  d.report.cyAxis = cstickY;
  d.report.right = RLight;
  d.report.left = LLight;
  GamecubeConsole.write(d);

  if ((currentGame == Melee) && (LatencyFix == true))
    delayMicroseconds(7200);
}

uint8_t fTwoIPNoReactivate(bool isLOW, bool isHIGH, bool& wasLOW, bool& wasHIGH, bool& lockLOW, bool& lockHIGH) {
  uint8_t control = 128;
  if (isLOW && isHIGH) {
    if (wasHIGH) {
      control = minValue;
      lockHIGH = true;
    }
    if (wasLOW) {
      control = maxValue;
      lockLOW = true;
    }
  }
  if (!isLOW && isHIGH && (lockHIGH == false)) {
    control = maxValue;
    wasHIGH = true;
    wasLOW = false;
    lockLOW = false;
  }
  if (isLOW && !isHIGH && (lockLOW == false)) {
    control = minValue;
    wasLOW = true;
    wasHIGH = false;
    lockHIGH = false;
  }
  if (!isLOW && !isHIGH) {
    wasHIGH = false;
    wasLOW = false;
    lockLOW = false;
    lockHIGH = false;
  }
  return control;
}

uint8_t fTwoIP(bool isLOW, bool isHIGH, bool& wasLOW, bool& wasHIGH) {
  uint8_t control = 128;
  if (isLOW && wasHIGH)
    control = minValue;
  if (isHIGH && wasLOW)
    control = maxValue;
  if (!isLOW && isHIGH) {
    control = maxValue;
    wasHIGH = true;
    wasLOW = false;
  }
  if (isLOW && !isHIGH) {
    control = minValue;
    wasLOW = true;
    wasHIGH = false;
  }
  return control;
}

uint8_t fNeutral(bool isLOW, bool isHIGH) {
  uint8_t control = 128;
  if (!isLOW && isHIGH)
    control = maxValue;
  if (isLOW && !isHIGH)
    control = minValue;
  return control;
}

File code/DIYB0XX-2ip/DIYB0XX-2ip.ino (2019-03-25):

#include "Nintendo.h"
/* This code uses the Nicohood Library
 * Use this code at your own risk
 * Code written by Simple Controllers and this code is open source.
 * Meaning its free to share, improve on, or anything you like!
 * Just remember to mention you used my code!
 * Edited by Danny for SmashB0XX
 *
 * [Crane]
 * For Smash4/U mode,
 *  Mod running, tilts, triggers(shields), and most firefox angles edited.
 *  Mods change running/walking speed. Direction, then mod1 gives perfect speed to ledgerun in smash4.
 *  Tilts now work with mod1.
 *  Triggers now give the analog value needed to shield in smash4/Ultimate. LRAStart now works too because of this
 *  FFox angles (b0xx method, c stick) now almost work properly. only mod1+diagonal+cright/left do not work (in smash4, not Ultimate). Can't figure out why.
    C stickless firefox angles function now.
 *
 * For Project M mode
 *  Tilts, firefox angles, shield drop angles (Axe method), and wavedash angles all fixed.
 *  Fixed bug where left and down were not working on SSS and menus.
 *
 *  All three modes are in this one program, so you don't have to keep swapping.
 *
 *  To launch in Melee mode, just plug in normally
 *  To launch in Ultimate/4 mode, hold B while plugging in.
 *  To launch in Project M mode, hold X while plugging in.
 *
 * Be sure to button check before starting a set, to confirm you are in the right mode.
 * If mod1+up makes you jump, or if mod1+down+B makes you neutral B, you are in the wrong mode. Check both of these.
 */
//This makes the controller bidirection data line on pin number8
CGamecubeConsole GamecubeConsole(8);      //Defines a "Gamecube Console" sending data to the console on pin 8
Gamecube_Data_t d = defaultGamecubeData;   //Structure for data to be sent to console

enum game
{
  Melee,
  PM,
  Ultimate
};

//This is needed but you don't need a controller on pin 7
CGamecubeController GamecubeController1(7);

//This is the pinout of the controller.  Can be changed to your liking.  I may have mixed up some of the tilt pins but you can change that physically in your build or through the code.  Just do test runs along the way.
const int A = 46;
const int B = 44;
const int X = 49;
const int Y = 31;
const int Z = 41;
const int START = 39;

const int R = 24;
const int L = 34;
//const int RLIGHT = 36; Only if using LightShield Button
//This is the value of analog shielding 74 is lightest possible on gamecube.  It varies from gamecube to dolphin no idea why.
//const int RLIGHTv = 74;

const int LEFT = 26;
const int RIGHT = 40;
const int UP = 48;
const int DOWN = 35;

const int MOD1 = 38;
const int MOD2 = 22;

const int CLEFT = 28;
const int CRIGHT = 50;
const int CUP = 30;
const int CDOWN = 51;

bool isLeft = false;
bool isRight = true;

game currentGame = Melee;

void setup()
{
  //This is establishing the pin assignments up there to input pins
  pinMode(A, INPUT_PULLUP);
  pinMode(B, INPUT_PULLUP);
  pinMode(X, INPUT_PULLUP);
  pinMode(Y, INPUT_PULLUP);
  pinMode(Z, INPUT_PULLUP);
  pinMode(START, INPUT_PULLUP);

  pinMode(R, INPUT_PULLUP);
  pinMode(L, INPUT_PULLUP);
  //pinMode(RLIGHT, INPUT_PULLUP);

  pinMode(LEFT, INPUT_PULLUP);
  pinMode(RIGHT, INPUT_PULLUP);
  pinMode(UP, INPUT_PULLUP);
  pinMode(DOWN, INPUT_PULLUP);

  pinMode(MOD1, INPUT_PULLUP);
  pinMode(MOD2, INPUT_PULLUP);

  pinMode(CLEFT, INPUT_PULLUP);
  pinMode(CRIGHT, INPUT_PULLUP);
  pinMode(CUP, INPUT_PULLUP);
  pinMode(CDOWN, INPUT_PULLUP);

  //this is just to turn off built in LED at start
  pinMode(LED_BUILTIN, OUTPUT);
  digitalWrite(LED_BUILTIN, LOW);

  if (digitalRead(B) == LOW)
    currentGame = Ultimate;
  if (digitalRead(X) == LOW)
    currentGame = PM;



  //This is needed to run the code.
  GamecubeController1.read();
}

void loop()
{
  //This resets and establishes all the values after the controller sends them to the console and helps with initial "zeroing"
  int pinA = 0;
  int pinB = 0;
  int pinX = 0;
  int pinY = 0;
  int pinZ = 0;
  int pinSTART = 0;

  int pinR = 0;
  int pinL = 0;
  int pinRLIGHT = 0;
  int pinLLIGHT = 0;

  int pinDLEFT = 0;
  int pinDRIGHT = 0;
  int pinDUP = 0;
  int pinDDOWN = 0;

  int mod1 = 0;
  int mod2 = 0;

  int pinCLEFT = 0;
  int pinCRIGHT = 0;
  int pinCUP = 0;
  int pinCDOWN = 0;

  int pinxAxisC = 128;
  int pinyAxisC = 128;

  int pinxAxis = 128;
  int xmod = 0;
  int pinyAxis = 128;

  int rightOne = 0;
  int leftOne = 0;
  int downOne = 0;
  int upOne = 0;

  int cUp = 0;
  int cDown = 0;
  int cLeft = 0;
  int cRight = 0;

  if (digitalRead(MOD1) == LOW && digitalRead(MOD2) == HIGH)mod1 = 1;
  if (digitalRead(MOD2) == LOW && digitalRead(MOD1) == HIGH)mod2 = 1;

  //SOCD method for left/right is 2ip
  if (digitalRead(LEFT) == LOW && isRight == true)
  {
    pinxAxis = 128-127;
    leftOne = 1;
  }
  else if (digitalRead(RIGHT) == LOW && isLeft == true)
  {
    pinxAxis = 128+127;
    rightOne = 1;
  }

  if (digitalRead(LEFT) == HIGH && digitalRead(RIGHT) == LOW){
    pinxAxis = 128+127;
    rightOne = 1;
    isRight = true;
    isLeft = false;
  }
  if (digitalRead(LEFT) == LOW && digitalRead(RIGHT) == HIGH){
    pinxAxis = 128-127;
    leftOne = 1;
    isLeft = true;
    isRight = false;
  }
  //

  //SOCD method for up/down is neutral
  if (digitalRead(DOWN) == HIGH && digitalRead(UP) == LOW){
    pinyAxis = 128+127;
    upOne = 1;
  }
  if (digitalRead(DOWN) == LOW && digitalRead(UP) == HIGH){
    pinyAxis = 128-127;
    downOne = 1;
  }

  //Reads CStick pins, same logic as controlstick values.
  if (digitalRead(CLEFT) == HIGH && digitalRead(CRIGHT) == LOW){
    pinxAxisC = 255;
    cRight = 1;
  }
  if (digitalRead(CLEFT) == LOW && digitalRead(CRIGHT) == HIGH){
    pinxAxisC = 0;
    cLeft = 1;
  }
  if (digitalRead(CDOWN) == HIGH && digitalRead(CUP) == LOW){
    pinyAxisC = 255;
    cUp = 1;
  }
  if (digitalRead(CDOWN) == LOW && digitalRead(CUP) == HIGH){
    pinyAxisC = 0;
    cDown = 1;
  }

  if (digitalRead(A) == LOW)pinA = 1;
  if (digitalRead(B) == LOW)pinB = 1;
  if (digitalRead(X) == LOW)pinX = 1;
  if (digitalRead(Y) == LOW)pinY = 1;
  if (digitalRead(Z) == LOW)pinZ = 1;
  if (digitalRead(START) == LOW)pinSTART = 1;



  //This is for digital shield.
  //[Crane] Also does a bit of analog shield for Smash4 and Ultimate
  if (digitalRead(R) == LOW) {
    pinR = 1;
    pinRLIGHT = 125;
  }
  if (digitalRead(L) == LOW) {
    pinL = 1;
    pinLLIGHT = 125;
  }
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

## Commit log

2019-01-03 Rearranging files
    [DetatchableB0XX.ipt, DetatchableB0XX.stl, DetatchableB0XXJustRJ45.stl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]
2019-01-03 name change
    [B0XX.stl, LID.stl]
2019-01-13 Updated folder names
    [Aluminum Acrylic plate v2.dwg, GCC holes.dwg]
2019-02-24 Fixed Melee wavedash angles
    [DIYB0XX-2ip.ino]
2019-03-13 GuitarHeroB0XX added, files reorganized
    [Aluminum Acrylic plate v2.dwg, GuitarHeroB0XX.dwg]
2019-03-25 fix PM wd angle
    [DIYB0XX-2ip.ino]
2019-05-13 Selected SOCD applies to Y axis now. R now overrides L.
2019-05-15 Neutral IP error fixed.
    [Aluminum Acrylic plate v2.dwg]
2019-07-11 Total remake of the code. Many Ultimate improvements. Msg me any issues.
    [DIYB0XX.ino]
2019-07-15 DPAD toggle switch functionality added as an option. Check readme
2019-08-01 PM Shield drop fix
    [DIYB0XX.ino]
2019-08-01 fixed fixed shield drop
    [DIYB0XX.ino]
2020-02-21 Fixed wiring diagram
2020-02-29 Fixed Min/Max Value (fixes PM)
    [DIYB0XX-v1.2.ino]
2020-03-11 Fixed Unclepunch L+DPad, Added a version with the smashbox pinout
    DIYSmashB0XX-vXXX.ino is the same as DIYB0XX-vXXX.ino, it just has its pinout altered to match the smashbox pinout. If you have a smashbox and know the pinout of the right hand ring and right hand pinky top row buttons, let me know. When I know those, I'll be able to make it so you can use the b0xx r2 light/midshield buttons.
    [DIYB0XX-v1.201.ino, DIYSmashB0XX-v1.201.ino]
2021-02-19 Added LayoutFiles
    [B0XX_24mm_TopPanel.dxf, GCCMX_SwitchPlate.dxf, Hammond_24mm_TopPanel.dxf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]
2021-03-31 Added some more layout files.
    [Hammond_24mm_TopPanel.dxf, iPadHitbox.dxf]
2021-04-12 Rename firmware to be more clear. Add Switch beta firmware.
2021-09-12 Add some layout file dxfs
    [Hammond_LargeCircleCover.dxf, Hammond_LargeCircleCover_20.dxf, Hammond_MX.dxf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]
